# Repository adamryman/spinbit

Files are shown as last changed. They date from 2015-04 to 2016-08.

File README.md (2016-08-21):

# SpinBit: A Wearable Rotation Counter
Katie Kemp, Adam Ryman, Isaac Perry
CSE 477, Spring 2015

spinbit is a piece of open source hardware that counts how many time you spin over time and send that data to your android phone.

See the [Final Report](./spinbit-final-report.pdf)

Web page that includes weekly reports: [spinbit.adamryman.com](http://spinbit.adamryman.com)

You can also see our [Poster](./poster.pdf). It was made in powerpoint in the file poster.pptx, and I, Adam, rendered the poster on linux so the fonts in the pdf may be off.

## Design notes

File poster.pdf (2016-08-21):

SpinBit

Processor | SD Card

Bluetooth Module

Mobile Device

Mobile Application

Gyroscope

### Problem:

Fitness devices, such as the fit bit, have become quite popular. This popularity demonstrates a desire to quantify physical activity. Currently the devices on the market measure little more than a simple pedometer. This works well for activities that are based on running but not for activities based on other modes of movement. Dancing is a popular physical activity and some methods of dancing in particular are rooted in spinning or twirling. Currently there is no fitness device that is designed to quantify spinning as it relates to dancing.

### Introducing SpinBit:

SpinBit is a fitness device specifically targeted for dancers. The device captures the rotations of your body and reports the intensity of your spinning. The accompanying mobile application is used to manage and view your spinning data. This gives you a new insight to your dancing, track trends over time and compete with your friends.

## What it does:

- Locally records relative times between users
spins
- Connects to mobile
device via bluetooth to
transfer data
- Mobile application
allows for user to
display spin data

### How it works:

- On record session initiation, SpinBit samples raw
gyroscope angular velocity data
- Angular velocity is
processed in real time to
determine “spin events”
- “Spin events” are recorded with relative time between events
- In idle mode, mobile device can request spin session
data via bluetooth
- Spin session data is
transferred via bluetooth
- Mobile application stores data and allows the user to visualize it.

# SpinBit: What’s your count?

## How you use it:

- Affix SpinBit to waist
using clip, with long side pointing down
- Turn device on and
press the button to start
recording a spin session
- After finished recording spin session, press
button again
- While device is on, the
mobile application may
be used to request spin
sessions
- Navigate to sessions on
mobile application to
view visualizations of
past spin sessions

### Looking forward:

Within this summer, we plan to release a crowd funding campaign to raise funding to release SpinBit to Seattle’s contra dancers. Using skills learned during this capstone, we plan to:
- Drastically reduce device size by using smaller battery, alternative storage hardware, stacked bluetooth/processor, and improved PCB layout
- Add additional app functionality such as, alternative data visualizations, sharing, and device configurations

Photo source:
https://www.theportlandcollection.com/contra-dancing/

Katie Kemp, Isaac Perry, Adam Ryman

spinbit.adamryman.com

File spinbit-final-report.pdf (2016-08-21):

# SpinBit: A Wearable Rotation Counter

## Katie Kemp, Adam Ryman, Isaac Perry CSE 477, Spring 2015

## ABSTRACT

The quantitative self-movement has created hundreds of niche devices for recording and analyzing specific details of everyday life. In this work, we present SpinBit, a lightweight wearable device that allows the user to locally record and share their average angular velocity. Our system uses a three axis gyroscope/accelerator to evaluate when a user completes a revolution and records that data locally, and allows the user to upload that data to a mobile android device for analysis and sharing. SpinBit has applications in performance arts and dancing where users may want to increase their spins over short or long periods of time and/or compete with other performers in spins. Furthermore, our device is awesome.

## Keywords

Spins, wearable, sensing, gyroscope

## 1. INTRODUCTION

In dancing and performance arts, performers often do not have the capacity to hold a multifunctional device (smartphone) on their person for clothing and/or weight restrictions. This drastically reduces their ability to gather data about their respective performances. We envision a wearable device that is very small and lightweight and self-contained that a user can clip to themselves to gather rotational data.

Currently all smartphones and several other devices that people use regularly have 3 axis gyroscopes already included. Theoretically spin detection should be trivial to implement on these devices in software, but the problem is that these device are either bulky, difficult to attach to a variety of clothing and/or an embedded device that is not easily programmed. SpinBit solves this problem by being designed specifically to do one thing, record spins, and do it very well.

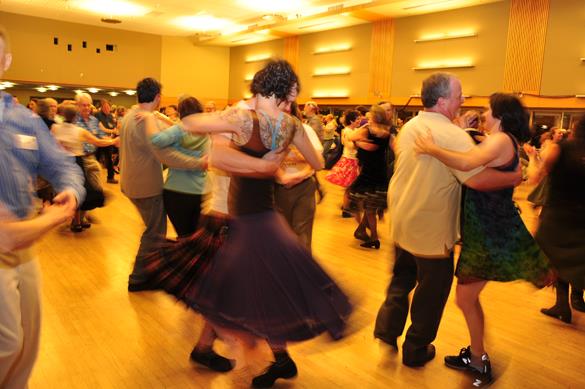
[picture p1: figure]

Figure 1. Contra Dancing is a type of dancing that involves lots of rotations, and thus a fun application of the SpinBit. [1]

## 2. THEORY OF OPERATION

Small lower power gyroscopes have been on the market for several years; their footprint is so small and their power usage so low that they have been incorporated into every smartphone ever created.

MEMS Gyroscopes (the type of gyroscope on circuit boards) use the Coriolis Effect to detect angular velocity along an axis of rotation. The premise is that there is a small object vibrating along a linear axis up and down, and this object affixed to a surrounding structure without impeding its vibrations [2]. If you take the plane that the object is vibrating within and rotate the plane, the object will want to keep moving in its linear direction and will move (from a non-rotating perspective) in the direction opposite of the rotation. The movement brings the vibrating object closer / farther from fixed walls and the capacitance between these objects can be amplified and outputted as the sensor values.

Mounting the gyroscope so that it is parallel to the user’s body in the standing vertical direction, we are able to detect the angular velocity of the user in the plane that is perpendicular to their standing direction.

This angular velocity data can then be integrated to find the users angular position relative to the time the sensor values were first read. Once this angular position exceeds 2*pi radians we record the time that has passed since the last event. This time is logged locally on the device and can be requested via Bluetooth.

## 3. SYSTEM IMPLEMENTATION DETAILS

The SpinBit system consists of a physical device clipped onto the user’s waist band and an app that this clip-on device connects to, where the user can see the spin data collected.

## 3.1 Hardware

The SpinBit uses an ATMEGA328 microcontroller as the central part of the system. There is a button on the device which when pressed by the user signals to the processor that it should begin collecting spin data. When the button is pressed a second time, the device exits data collection mode and waits for a Bluetooth signal from the android phone app requesting spin data.

The microcontroller is connected to a MPU-6050 triple-axis combined gyroscope and accelerometer. When in data collection mode, the processor requests acceleration data from the gyroscope.

The SpinBit stores spinning data in a directory of text files hosted by a microSD card. Every time the processor determines that a spin has happened it notes the time since the device entered data collection mode, and saves this value into storage in a text file created for the current spin session. The SpinBit uses a Bluetooth to communicate with the android application. When the application requests data, the device sends the oldest spin session text file on the microSD card over Bluetooth to the application. When the SpinBit receives conformation from the app that a data set has been successfully sent, it deletes the text file associated with the oldest spin session currently in storage. Whenever the device is powered on and not recording, it is waiting for a command from the mobile device.

There is a reset button that will not be easily accessible to the user as well as pin headers that we used for debugging and programming. The power switch is located on the side, so as to be easily accessible to the user. The SpinBit uses a 3.7V lithium polymer re-chargeable battery. The board that we designed includes as charging IC and micro USB port for charging the battery.

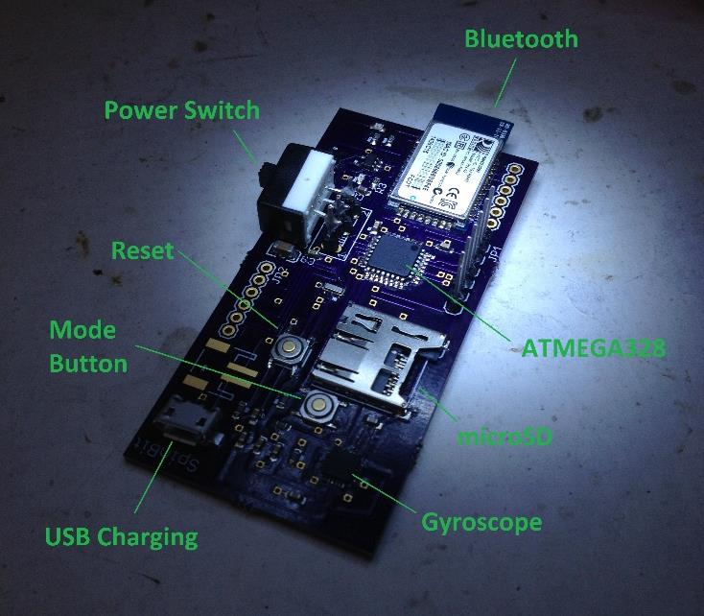
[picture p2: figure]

Figure 2. In an effort to make our prototype device as small as possible, we custom designed the PCB used.

## 3.2 Data Processing

All data processing is currently done on the SpinBit in real time concurrent with data collection. When in data collection mode, the processor requests the angular velocity from the gyroscope. Because of the orientation that the gyroscope is mounted in, we look just at the Y component of the gyroscope data; this component corresponds to the plane of rotation experienced by a dancer wearing the SpinBit in the proper orientation. The value read by the processor from the gyroscope is adjusted based on the current level of sensitivity of the gyroscope to obtain a positional value in degrees. If the processor determines that the user has not changed direction, it adds the degrees rotated to a running sum. When this sum reaches 360 degrees, a spin is logged. If the processor determines that the user has changed direction it checks if the sum is over certain threshold. If the sum is over this threshold it logs a spin before resetting the sum.

The prototype that we are demoing has a simpler version of the data processing on it that does not check to see how far the user has rotated when a change of direction occurs.

## 3.3 Android Application

The main features of the app are to retrieve data sets from the SpinBit and display data sets to the user. These main features require a number of secondary features: Bluetooth configuration; establishing a Bluetooth connection between the mobile device and the SpinBit; requesting datasets into and putting them into permanent storage; and enabling the user to browse different data sets.

The home page of the app has four buttons: “My Spins”, “Download from SpinBit”, “Reconnect” and “Set Up”. “My Spins” will display a list of all the data sets that have previously been downloaded. “Download” requests a data set from the SpinBit and saves it into permanent storage. “Reconnect” initiates the app side of the Bluetooth connection with the SpinBit. “Set Up” allows the user to specify the unique name of the specific SpinBit this mobile application is capable of connecting to.

Before the user employs any of these features there is some initial setup. First, the user must pair their mobile device with the SpinBit. This is done through the settings of the mobile device. Bluetooth should be turned on and the device is visible. Select the name of your SpinBit and the devices will be paired. Now the app needs to connect to the SpinBit.

Initially the app is incapable to making a Bluetooth connection to a SpinBit. In order for the mobile device to connect, the application needs to know identifying information about the Bluetooth module the SpinBit is using to make a connection. The homepage of the app has a “Set Up” button. Pressing this button brings up a dialog where the user can enter the name of the Bluetooth module in the SpinBit. The name is saved as a preference and will persist even after the app is closed. At any time the user can press this button to change the name of the SpinBit the app is able to connect to. This must be done at least once before any other of the apps functions can operate, but once it is done the app is now fully operational.

If the app has a name for the SpinBit it will connect to, it will automatically connect at startup. After specifying a name or if the connection was disturbed, the “Reconnect” button will initiate a new connection between the application and the SpinBit the app knows the name of.

Once the app has been properly set up and is connected with SpinBit, it is ready to receive data. To request a data set from the SpinBit press the “Download” button. This sends a request to the SpinBit, which must be in transfer mode. The SpinBit will send characters over Bluetooth to the mobile device; these characters are stored in a buffer in the app until a specific character sequence that signifies the end of the data set is added to the buffer. This sequence is a newline character followed by a return character (“\r\n”). Once a whole data set has been received a data set object is instantiated which holds the data from the SpinBit, a Timestamp for this data set and a name that the user can set later. This data set object it is added to a library of data set objects, which is implemented with a List. This library is regularly backed up and saved to a JSON file. The data sets in this library can be accessed by the user.

The app lets the user browse their saved data sets, tag information about their data sets, and view visualizations of the data sets. Pressing the “My Spins” button from the home screen displays a list of datasets, ordered chronologically. The data sets of spins have names and timestamps associated with them; these are displayed in the list along with the total number of spins in that set. The user is able to click on a data set and is taken to a new page. This page displays the name of the data set, a graph of the data. The data that is saved are time periods in milliseconds between spins captured by the SpinBit. This data is converted into angular velocity in complete spins per second and the app generates a graph of this trend for the user. Below the graph there are buttons which launch dialogs that allow the user to specify a name for the data set, and modify the date and time for this data set.

## 4. EXPERIMENTAL PROCEDURE AND RESULTS

Most of the testing for the SpinBit consisted of testing each individual section. For instance, we tested parts on a bread board, got what we had connected working before we added more parts. Once we had things working on a breadboard we designed a PCB based off of our breadboard design.

## 4.1 Breadboard Design and Testing

After device conception we quickly ordered parts to build a functional prototype on a breadboard. We used this prototype to test various assumptions about product feasibility. To keep our budget low we ordered the cheapest breakout board components we could find. We chose the atmega processor with the Arduino development board because of it’s easy of use and heavy community support and documentation. After hooking up and configuring each component we built three basic systems, one to put data onto a SD card, one to send data from the SD card to Bluetooth, and one to process the sensor data.

## 4.2 Tests of Spin Detection

Initially we took transferred our raw sensor data to a PC and used Python to get a sense of what processing techniques would give us clean spin detection. The first task was correlating the raw sensor values with actual angular velocities and positions; we did this through a combination of reading our datasheets to find theoretical correlated values and then doing controlled spins to tweak these values for a full 360 degree rotation. After being able to reliably detect a rotation while moving in a single direction, we started work on detecting when the user changed directions and how to deal with partial spins. We eventually determined that we could sense if the user was changing direction by storing a small amount of the previous sensor values in memory and checking if the running sum of sensor values were trending in the other rotational direction. If this was the case we would check how close the user was to completing a rotation and if they were within 80% of a spin we would count that as a spin event. This 80% of a spin check was also run at the end of a spin session to determine if the user had almost made a spin before ending the session.

We then later moved a simpler version of this processing code to the embedded device code.

## 4.3 App Design and Testing

The app was built in many stages, each adding a single feature at a time. The first feature implemented was the home screen, containing four buttons that initially did nothing.

The next step was to implement model object classes that represent a single data set; they store the data, the date, the time and the name of the data set.

The next hurdle was connecting from an android app to an Arduino over Bluetooth. A separate app was made that would simply be able to communicate with an Arduino and toggle an LED. Using an open source app that implemented a Bluetooth connection as a guide, the app was able to connect with another Bluetooth device and exchange data. Then we wrote an Arduino sketch which would listen to serial communication and if it received the correct character it would toggle the LED connected to one of its’ digital output pins. We were able to verify that the Bluetooth connection was working because pressing a button on the app would toggle the state of the LED. Once this was working properly, we added the Bluetooth management code to the home screen implementation in the original app. Before we could test this, we needed to build a SpinBit emulator on an Arduino; this device would wait for a data request, generate a random data set and send it over serial through a Bluetooth module to the application. This was verified using console logs in both the Android and Arduino software. We then added the details of handling data coming from the emulated SpinBit, using that data to instantiate the model objects and save them in a collection. This step was also verified using console logs in the Android application.

While this data could be stored in a collection available to the app, this collection would not persist if the app was closed. We next added the ability to save the contents of the data set collection in a local file on the mobile device. This was verified by logging the contents of the collection to the console, closing the app, and then logging the collection to the console again; the system works properly if the contents of the collection didn’t change after closing the app.

Once the data persisted, the next goal was to add a screen that would allow the user to browse the data sets. There is a screen in the Android library that accepts a collection and displays the contents in a list-view. We were able to confirm this feature was working properly when the contents of the collection logged to the console matched with what was displayed to the user when they launched the new screen.

The purpose of browsing data sets is to choose one and have it visualized for the user. We wanted to create a graph of a single dataset for the user. We were able to find an Android library that would accept an array of data and graph it on a screen. We built a separate app that took an array of fake data and graphed it for the user. It was easy to verify the library worked because we knew how the fake data set should look when graphed. Once this was working properly, we added a feature that when the user clicks on an item in the list-view of data sets, it would first launch a new screen. It also passed the data set to the new screen. In this new screen we included the graphing library and graphed the dataset for the user. We confirmed this was working by comparing the graphs to the data sets logged in the console.

The last features added were displaying more information to the user about the data set with the graph, and adding buttons that let the user modify this information.

We then extensively tested the app by doing everything in our power to break the app. One of the first noticeable bugs was that values would reset (including the values that maintain the Bluetooth connection) when the orientation of the mobile device changed. We were able to fix this issue by changing a setting that forces all of the apps’ screens to retain their state through an orientation change. This also allowed the app to retain its state when it is paused, in the background.

Another issue to be tested was protecting the integrity of the data. We tried exiting the app and shutting down the device in places where the data was being handled. Because the data is saved in a local file and backed up any time it was changed the data was sufficiently protected from corruption.

The last outlet for bugs was the Bluetooth connection. The app was able to handle various edge cases of the data sets: an empty data set, a very large data set, a data set containing negative numbers and a data set containing zeros. Measures were taken in the design of the app to handle each of these scenarios in a reasonable way that doesn’t break the app or cause an inconvenience for the user.

## 4.4 Full-System Testing

The app and the SpinBit device were designed and built separately and the last step for each side was integrating the two halves of the product. The only interface between the two sides of the system is the Bluetooth communication. Because each side was able to independently connect and communicate with other devices, we were able to verify Bluetooth was working for each side properly;

as a result we were able to develop and test both sides knowing only each other’s Bluetooth interface. Partially through the design process, the two teams met to decide on a protocol for transferring data over Bluetooth so that the integration would be seamless. We then went on to design the rest of the project with this protocol in mind. The first time we attempted to integrate the app with the SpinBit we were able to successfully transfer data, save it to the app and display a graph of that data. When gathering this data we periodically spun slowly to fast so that the graph of the data would be recognizable. The graph for this data demonstrated this expectation.

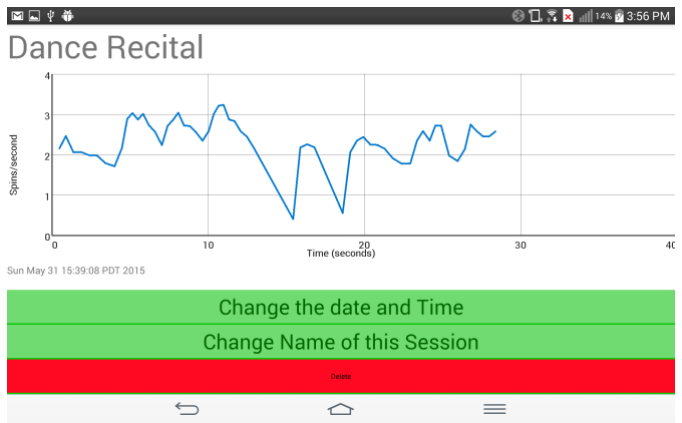
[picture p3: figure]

Figure 3. The graph of a dance session displayed on the mobile device; the peaks and valleys correspond to when the tester was spinning quickly and slowly.

## 5. CHALLENGES

One of the main challenges that we faced was programming the microcontroller on our PCB. When designing the PCB we believed we would be able to program the processor with FTDI pins that were intentionally exposed and soldered to pin headers. It turned out that this was not sufficient for flashing the bootloader onto the microcontroller chip that we are using. In the end we soldered wires directly to the ATMEGA in order to program it. This was a slow process and it frequently required reattaching and often re-soldering wires to the processor just to load a new program onto it; but this did in fact work. We still don’t know how to properly program with the FTDI, and so have been programming with an Arduino Uno as ISP. This means that we are programming at 5V which was not our intent when designing the device. This resulted in various components on the PCB being programmed at a higher voltage than they were specified to be. So while programming we fried our Bluetooth module. Our solution to this was to solder on the 5V Bluetooth module that we used for our breadboard prototype and run it at 3.3V. This seems to be working fine so far.

## 6. FUTURE WORK AND DISCUSSION

In the future we would like to make the device much smaller. We think that this could be done through changing some of the PCB components. The first change that we would make is to use an SPI memory chip instead of the microSD card. The IC for the SPI memory will take up much less space than current microSD card reader. The only downside to using the SPI memory is that we would need to write our own code for memory management instead of being able to use the Arduino SD library.

The second change that we would make is to the Bluetooth module. Instead of the current breakout board that we are using, we would ideally use a low power Bluetooth module. It would also be an improvement if we got a stacked chip such as the RFduino where the Bluetooth module is stacked directly on top of the microcontroller. If we do use a Bluetooth module that is lower power, then our device as a whole would be using less power. Switching from microSD to SPI chip should also reduce the power consumption of parts on the board. With both of these power reductions it could be possible to use a much smaller battery. With all of these size reductions in parts the device as a whole could be much smaller and less noticeable when clipped onto the waistband of the user.

While developing this device there was a lot of discussion as to what should count as a “spin”. Potential users of the SpinBit whom we spoke with all had very different opinions as to what they believe counts as a “spin”. We would like to add multiple spin options that the user can select from. For instance the user could want a spin to be counted only when they have rotated a full 360 degrees, or they may think that moving 180 degrees and then changing directions should count as a spin. There are several ways this could be implemented. One way would be for the user to send a signal from the phone app to tell the microcontroller on the device to process data differently. If we were to implement it this way it would not be possible to change how spins were counted after the data had already been collected. The second way that we could implement this feature would be to process data on the phone side of the system. If we were to implement the feature this way we would have to send all of the data collected by the gyroscope during the spin session over Bluetooth, which could potentially be a lot of data if the session lasts for several hours. The benefit of this would be that the user could go back to logged spin sessions stored on their phone and change the way that spins were processed.

## 7. CONCLUSION

This project was developing the SpinBit, a device for detecting, logging and quantifying the spinning motion of the user. The device is lightweight and can be used completely independently of any other device. It uses real time gyroscope data processing to detect and record spins locally and uses Bluetooth to transfer this data to a mobile device for viewing and sharing. We envision this device to be used by dancers and performance artists to improve their work and satisfy their competitive spirit.

## 8. ACKNOWLEDGMENTS

Our thanks to the CSE and EE departments. Especially to Professor Reynolds and all the people in his lab who helped us when we screwed stuff up.

## 9. REFERENCES

[1] Theportlandcollection.com, 'Contra Dancing', 2015. [Online]. Available: https://www.theportlandcollection.com/contra-dancing
[2] Electroiq.com, 'Introduction to MEMS gyroscopes', 2015.
[Online]. | Available:
http://electroiq.com/blog/2010/11/introduction-to-mems-gyroscopes/

# Columns on Last Page Should Be Made Equal Length

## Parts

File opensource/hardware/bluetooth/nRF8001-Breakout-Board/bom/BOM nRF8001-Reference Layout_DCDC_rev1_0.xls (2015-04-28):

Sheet: Mouser BOM - Table 1
nRF8001 core circuitry Bill of Materials
DC/DC converter enabled
Designator | Value | Footprint | Manufacturer Part # | Mouser Part # | Mouser Price | Quantity | Item Total | Comment
C1, C2 | 18pF | 0603 | VJ0603A100GXACW1BC | 77-VJ0603A100GXACBC | 0.098 | 5 | 0.49 | NP0 +/- 2%
C13, C14 | 9pF | 0603 | GRM1885C1H9R0BZ01D | 81-GRM1885C1H9R0BZ01 | 0.098 | 5 | 0.49 | NP0 +/- 2%
C3 | 2.2nF | 0603 | 77-VJ0603A222GXJPBC | VJ0603A222GXJPW1BC | 0.142 | 3 | 0.426 | X7R +/- 10%
C4 | Not mounted | 0603 |  |  |  | 3 | 0
C5 | 1.8pF | 0603 | VJ0603A1R8BXXCW1BC | 77-VJ0603A1R8BXXCBC | 0.087 | 3 | 0.261 | NP0 +/-0.1pF
C6 | 1.2pF | 0603 | VJ0603A1R2BXACW1BC | 77-VJ0603A1R2BXACBC | 0.087 | 3 | 0.261 | NP0 +/-0.1pF
C7, C9 | 1.0µF | 0603 | C1608X7R1C105KT | 810-C1608X7R1C105K | 0.076 | 5 | 0.38 | X7R +/- 10%
C8 | 1.0nF | 0603 | CC0603KRX7R9BB102 | 603-CC603KRX7R9BB102 | 0.098 | 3 | 0.294 | X7R +/- 10%
C10, C12 | 100nF | 0603 | 0603YC104KAT2A | 581-060316C104K | 0.044 | 5 | 0.22 | X7R +/- 10%
C11 | 33nF | 0603 | C0603C333K4RACTM | 80-C0603C333K4RACTM | 0.076 | 3 | 0.228 | X7R +/- 10%
L1 | 8.2nH | 0603 | CI160808-8N2J | 652-CI160808-8N2J | 0.055 | 3 | 0.165 | High frequency chip inductor +/-5%
L2 | 5.6nH | 0603 | 744761056C | 710-744761056C | 0.36 | 3 | 1.08 | High frequency chip inductor +/-5%
L3 | 3.9nH | 0603 | B82496C3399J | 871-B82496C3399J | 0.382 | 3 | 1.146 | High frequency chip inductor +/-5%
L4 | 10µH | 0603 | MLZ1608M100WT | 810-MLZ1608M100W | 0.087 | 3 | 0.261 | Chip inductor, IDC,min = 50mA, +/-20%
L5 | 15nH | 0603 | L0603C15NJRMST | 80-L0603C15NJRMST | 0.131 | 3 | 0.393 | High frequency chip inductor +/-10%
R1 | 22k | 0603 | AC0603FR-0722KL | 603-AC0603FR-0722KL | 0.022 | 3 | 0.066 | +/-1%
U1 | nRF8001 | QFN32 | nRF8001-R2Q32-T | 949-NRF8001-R2Q32-T | 4.98 | 2 | 9.96 | QFN32 5x5 mm package
X1 | U1 | 3.2 x 2.5 mm | ABM8G-16.000MHZ-B4Y-T | 815-ABM8G-16-B4Y-T | 1.27 | 2 | 2.54 | SMD-3225, 16 MHz, CL=18pF, +/-30 ppm
X2 | 32.768kHz | 3.2 x 1.5 mm | ABS10-32.768KHZ-9-T | 815-ABS10-32.768K9T | 1.08 | 2 | 2.16 | 32.768kHz, Cl=9pF, ±20ppm
 | 2.4GHz |  | A24-HASM-450 | 888-A24-HASM-450 | 6.55 | 1 | 6.55 | Antenna
 |  |  |  |  |  |  | 0
Total |  |  |  |  | 9.173 |  | 27.371
Other Components
Designator | Value | Footprint | Manufacturer Part # |  | Price | Quantity | Item Total | Comment
PCB substrate | FR4 laminate | 18.4 x 16.7 mm |  |  | 1 | 10 | 10 | 2 layer, thickness 1.6 mm, from SeeedStudio
RP SMA |  |  |  |  | 1.95 | 2 | 3.9 | Sparkfun RP SMA
Total |  |  |  |  | 2.95 |  | 13.9
GRAND TOTAL | 41.271

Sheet: Mouser BOM Import - Table 1
C1, C2 | 77-VJ0603A100GXACBC | 10
C13, C14 | 81-GRM1885C1H9R0BZ01 | 10
C3 | VJ0603A222GXJPW1BC | 5
C4 |  | 5
C5 | 77-VJ0603A1R8BXXCBC | 5
C6 | 77-VJ0603A1R2BXACBC | 5
C7, C9 | 810-C1608X7R1C105K | 10
C8 | 603-CC603KRX7R9BB102 | 5
C10, C12 | 581-060316C104K | 10
C11 | 80-C0603C333K4RACTM | 5
L1 | 652-CI160808-8N2J | 5
L2 | 710-744761056C | 5
L3 | 871-B82496C3399J | 5
L4 | 810-MLZ1608M100W | 5
L5 | 80-L0603C15NJRMST | 5
R1 | 603-AC0603FR-0722KL | 5
U1 | 949-NRF8001-R2Q32-T | 2
X1 | 815-ABM8G-16-B4Y-T | 2
X2 | 815-ABS10-32.768K9T | 2

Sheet: Newark BOM - Table 1
nRF8001 core circuitry Bill of Materials
DC/DC converter enabled
Designator | Value | Footprint | Manufacturer Part # | Newark Part # | Newark Price | Comment
C1, C2 | 18pF | 0603 | VJ0603A100GXACW1BC |  |  | NP0 +/- 2%
C13, C14 | 9pF | 0603 | GRM1885C1H9R0BZ01D |  |  | NP0 +/- 2%
C3 | 2.2nF | 0603 | 77-VJ0603A222GXJPBC (http://ca.mouser.com/ProductDetail/Vishay-Vitramon/VJ0603A222GXJPW1BC/) |  |  | X7R +/- 10%
C4 | Not mounted | 0603
C5 | 1.8pF | 0603 | VJ0603A1R8BXXCW1BC |  |  | NP0 +/-0.1pF
C6 | 1.2pF | 0603 | VJ0603A1R2BXACW1BC |  |  | NP0 +/-0.1pF
C7, C9 | 1.0µF | 0603 | C1608X7R1C105KT |  |  | X7R +/- 10%
C8 | 1.0nF | 0603 | CC0603KRX7R9BB102 |  |  | X7R +/- 10%
C10, C12 | 100nF | 0603 | 0603YC104KAT2A |  |  | X7R +/- 10%
C11 | 33nF | 0603 | C0603C333K4RACTM |  |  | X7R +/- 10%
L1 | 8.2nH | 0603 | CI160808-8N2J |  |  | High frequency chip inductor +/-5%
L2 | 5.6nH | 0603 | 744761056C |  |  | High frequency chip inductor +/-5%
L3 | 3.9nH | 0603 | B82496C3399J |  |  | High frequency chip inductor +/-5%
L4 | 10µH | 0603 | MLZ1608M100WT |  |  | Chip inductor, IDC,min = 50mA, +/-20%
L5 | 15nH | 0603 | L0603C15NJRMST |  |  | High frequency chip inductor +/-10%
R1 | 22k | 0603 | AC0603FR-0722KL |  |  | +/-1%
 | nRF8001 | QFN32 | nRF8001-R2Q32-T |  |  | QFN32 5x5 mm package
X1 | U1 | 3.2 x 2.5 mm | ABM8G-16.000MHZ-B4Y-T |  |  | SMD-3225, 16 MHz, CL=18pF, +/-30 ppm
X2 | 32.768kHz | 3.2 x 1.5 mm | ABS10-32.768KHZ-9-T |  |  | 32.768kHz, Cl=9pF, ±20ppm
PCB substrate | FR4 laminate | 18.4 x 16.7 mm |  |  |  | 2 layer, thickness 1.6 mm
Total

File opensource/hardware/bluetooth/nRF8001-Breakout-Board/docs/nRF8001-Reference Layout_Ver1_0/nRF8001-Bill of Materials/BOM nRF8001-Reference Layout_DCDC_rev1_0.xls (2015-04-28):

Date: 2010-12-20
nRF8001 core circuitry Bill of Materials
DC/DC converter enabled
Designator | Value | Footprint | Comment
C1, C2, C13, C14 | 15pF | 0402 | NP0 +/- 2%
C3 | 2.2nF | 0402 | X7R +/- 10%
C4 | Not mounted | 0402
C5 | 1.8pF | 0402 | NP0 +/-0.1pF
C6 | 1.2pF | 0402 | NP0 +/-0.1pF
C7, C9 | 1.0µF | 0603 | X7R +/- 10%
C8 | 1.0nF | 0402 | X7R +/- 10%
C10, C12 | 100nF | 0402 | X7R +/- 10%
C11 | 33nF | 0402 | X7R +/- 10%
L1 | 8.2nH | 0402 | High frequency chip inductor +/-5%
L2 | 5.6nH | 0402 | High frequency chip inductor +/-5%
L3 | 3.9nH | 0402 | High frequency chip inductor +/-5%
L4 | 10µH | 0603 | Chip inductor, IDC,min = 50mA, +/-20%
L5 | 15nH | 0402 | High frequency chip inductor +/-10%
R1 | 22k | 0402 | +/-1%
U1 | nRF8001 | QFN32 | QFN32 5x5 mm package
X1 | 16MHz | 3.2 x 2.5 mm | SMD-3225, 16 MHz, CL=9pF, +/-50 ppm
X2 | 32.768kHz | 3.2 x 1.5 mm | SMD-3215, 32.768kHz, Cl=9pF, ±20ppm
PCB substrate | FR4 laminate | 18.4 x 16.7 mm | 2 layer, thickness 1.6 mm

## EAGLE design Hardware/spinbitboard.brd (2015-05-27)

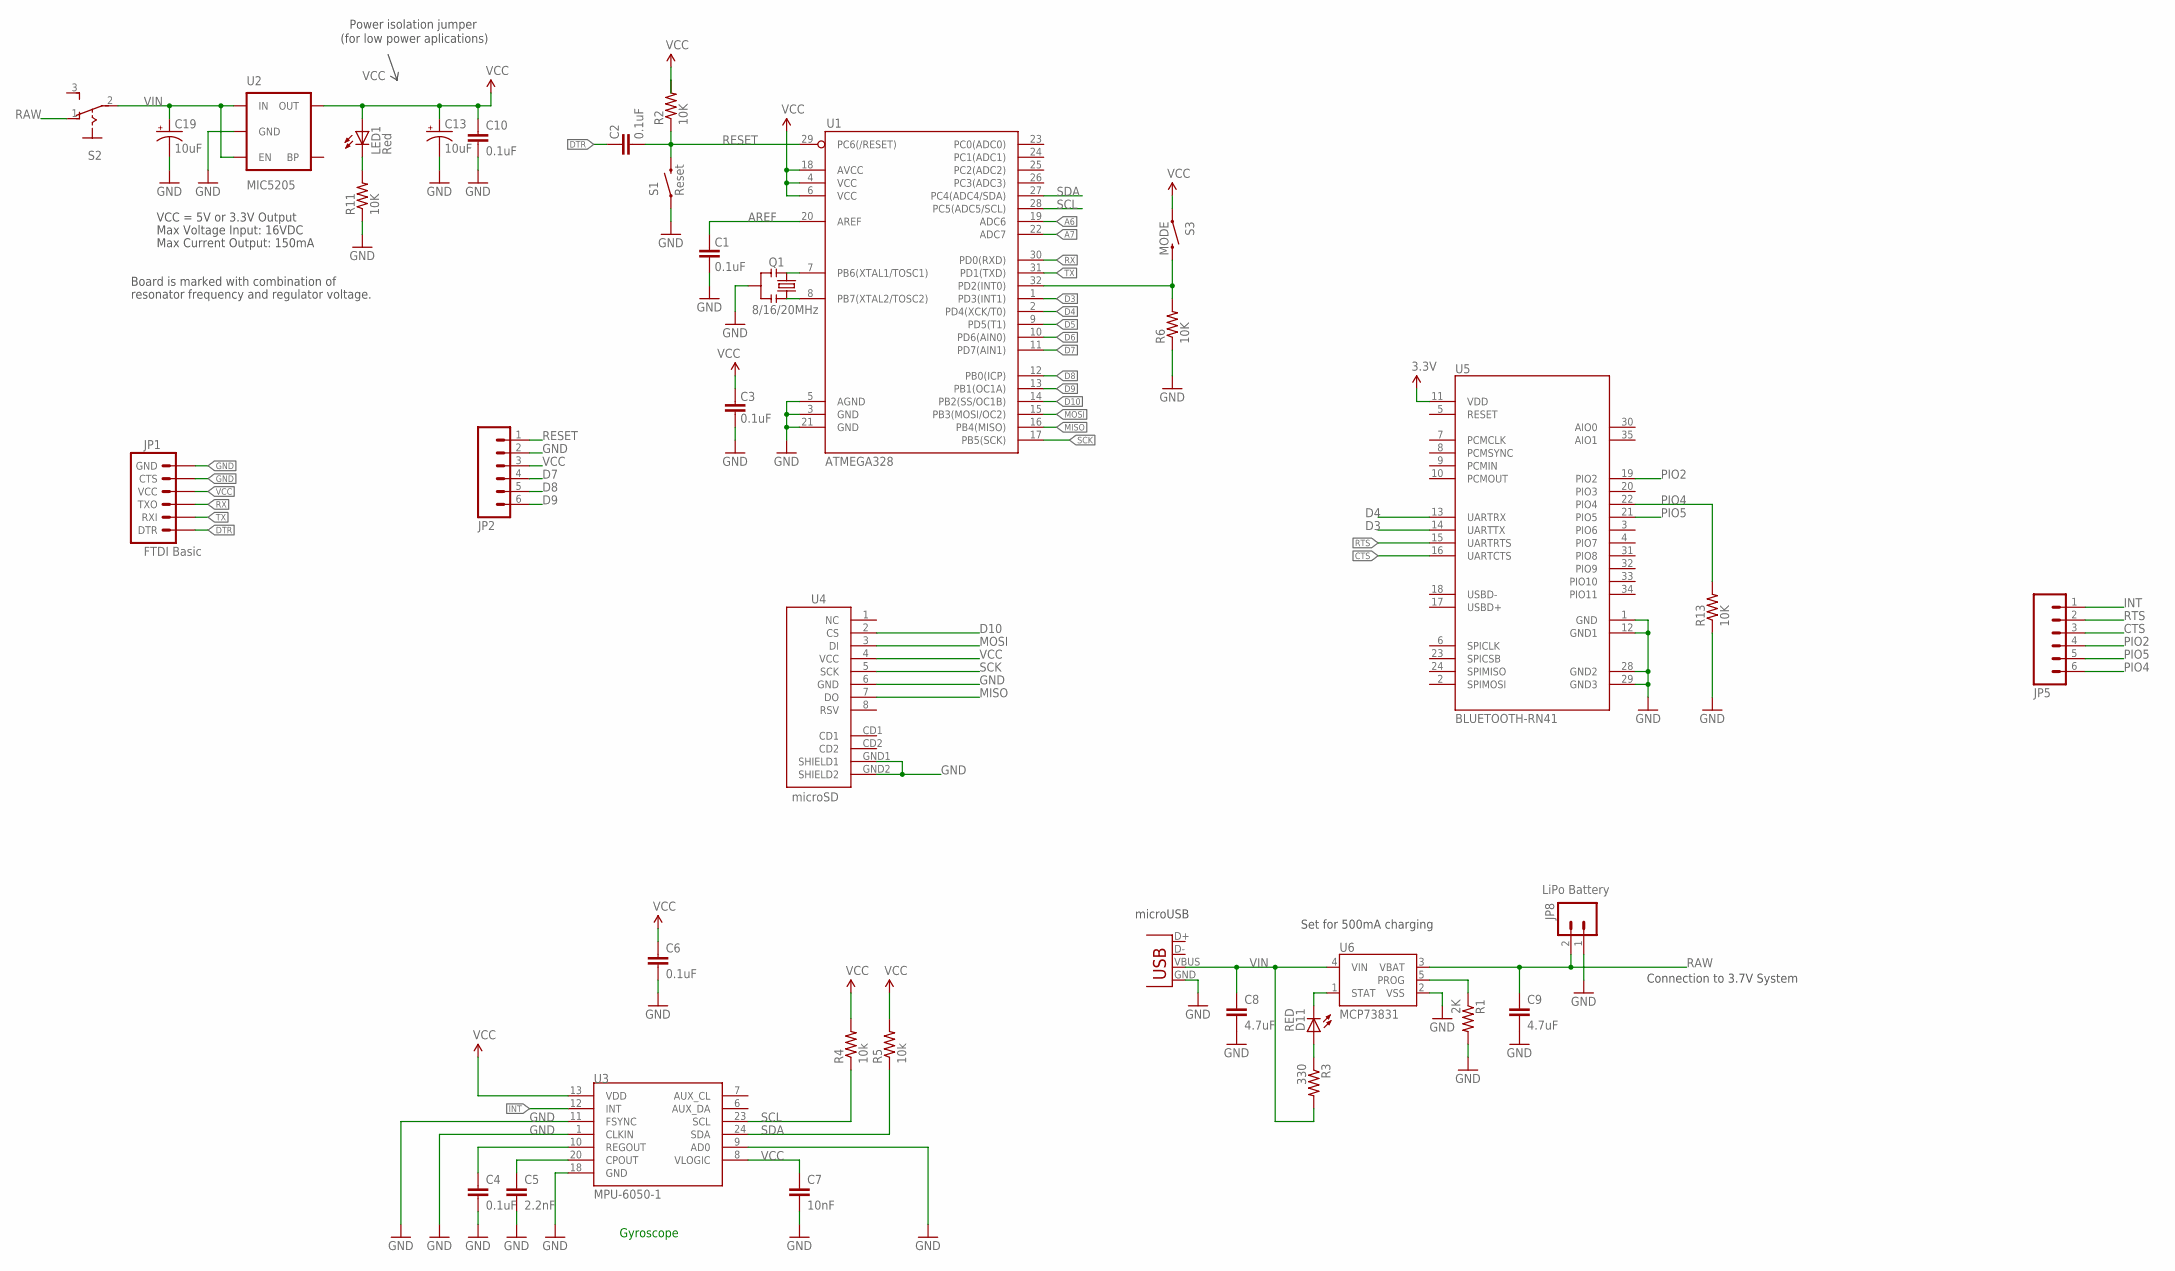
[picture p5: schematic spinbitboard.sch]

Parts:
C1, C2, C3, C4, C6, C10: 0.1uF; 0603-CAP
C5: 2.2nF; 0603-CAP
C7: 10nF; 0603-CAP
C8, C9: 4.7uF; C0603
C13, C19: 10uF; EIA3216
D11: RED; LED-0603
JP1: FTDI Basic; 1X06
JP2, JP5: M06SIP; 1X06
JP8: LiPo Battery; JST-2-SMD
LED1: Red; 0603-LED-ALT1
Q1: 8/16/20MHz; RESONATOR-SMD-1:1
R1: 2K; R0603
R2, R6, R11, R13: 10K; 0603-RES
R3: 330; R0603
R4, R5: 10k; 0603-RES
S1: Reset; TACTILE-SWITCH-SMD-ALT01
S2: 255SB
S3: MODE; TACTILE-SWITCH-SMD-ALT01
U1: ATMEGA328; TQFP32-08
U2: MIC5205; SOT23-5
U3: MPU-6050-1; QFN-24-4MM2
U4: microSD; MICRO-SD-SOCKET-PP
U5: BLUETOOTH-RN41; RN41
U6: MCP73831; SOT23-5
X1: Micro USB; USB-MICROB

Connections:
3.3V: C6.1, R4.2, R5.2, S3.1, S3.2 (1), U3.13 (VDD)
A6: U1.19 (ADC6)
A7: U1.22 (ADC7)
AREF: C1.2, U1.20 (AREF)
CTS: JP5.3, U5.16 (UARTCTS)
D2: R6.2, S3.3 (2), S3.4 (2), U1.32 (PD2(INT0))
D3: U1.1 (PD3(INT1)), U5.14 (UARTTX)
D4: U1.2 (PD4(XCK/T0)), U5.13 (UARTRX)
D5: U1.9 (PD5(T1))
D6: U1.10 (PD6(AIN0))
D7: JP2.4, U1.11 (PD7(AIN1))
D8: JP2.5, U1.12 (PB0(ICP))
D9: JP2.6, U1.13 (PB1(OC1A))
D10: U1.14 (PB2(SS/OC1B)), U4.2 (CS)
DTR: C2.2, JP1.1 (DTR)
GND: C1.1, C3.1, C4.2, C5.2, C6.2, C7.2, C8.2, C9.2, C10.2, C13.C (-), C19.C (-), JP1.5 (CTS), JP1.6 (GND), JP2.2, JP8.1, Q1.2, R1.2, R6.1, R11.1, R13.1, S1.1, S1.2 (1), U1.3 (GND), U1.5 (AGND), U1.21 (GND), U2.2 (GND), U3.1 (CLKIN), U3.9 (AD0), U3.11 (FSYNC), U3.18 (GND), U4.6 (GND), U4.GND1 (SHIELD1), U4.GND2 (SHIELD2), U5.1 (GND), U5.12 (GND1), U5.28 (GND2), U5.29 (GND3), U6.2 (VSS), X1.GND
INT: JP5.1, U3.12 (INT)
MISO: U1.16 (PB4(MISO)), U4.7 (DO)
MOSI: U1.15 (PB3(MOSI/OC2)), U4.3 (DI)
unnamed: Q1.3, U1.8 (PB7(XTAL2/TOSC2))
unnamed: Q1.1, U1.7 (PB6(XTAL1/TOSC1))
unnamed: LED1.C, R11.2
unnamed: C5.1, U3.20 (CPOUT)
unnamed: C4.1, U3.10 (REGOUT)
unnamed: D11.A, R3.1
PIO2: JP5.4, U5.19 (PIO2)
PIO4: JP5.6, R13.2, U5.22 (PIO4)
PIO5: JP5.5, U5.21 (PIO5)
PROG: R1.1, U6.5 (PROG)
RAW: C9.1, JP8.2, S2.1 (O), U6.3 (VBAT)
RESET: C2.1, JP2.1, R2.1, S1.3 (2), S1.4 (2), U1.29 (PC6(/RESET))
RTS: JP5.2, U5.15 (UARTRTS)
RX: JP1.3 (TXO), U1.30 (PD0(RXD))
SCK: U1.17 (PB5(SCK)), U4.5 (SCK)
SCL: R4.1, U1.28 (PC5(ADC5/SCL)), U3.23 (SCL)
SDA: R5.1, U1.27 (PC4(ADC4/SDA)), U3.24 (SDA)
STAT: D11.C, U6.1 (STAT)
TX: JP1.2 (RXI), U1.31 (PD1(TXD))
VCC: C3.2, C7.1, C10.1, C13.A (+), JP1.4 (VCC), JP2.3, LED1.A, R2.2, U1.4 (VCC), U1.6 (VCC), U1.18 (AVCC), U2.5 (OUT), U3.8 (VLOGIC), U4.4 (VCC), U5.11 (VDD)
VIN: C8.1, C19.A (+), R3.2, S2.2, U2.1 (IN), U2.3 (EN), U6.4 (VIN), X1.VBUS

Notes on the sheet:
Max Voltage Input: 16VDC
Max Current Output: 150mA
Board is marked with combination of
resonator frequency and regulator voltage.
VCC = 5V or 3.3V Output
Power isolation jumper
(for low power aplications)
Gyroscope
Set for 500mA charging
Connection to 3.7V System
microUSB

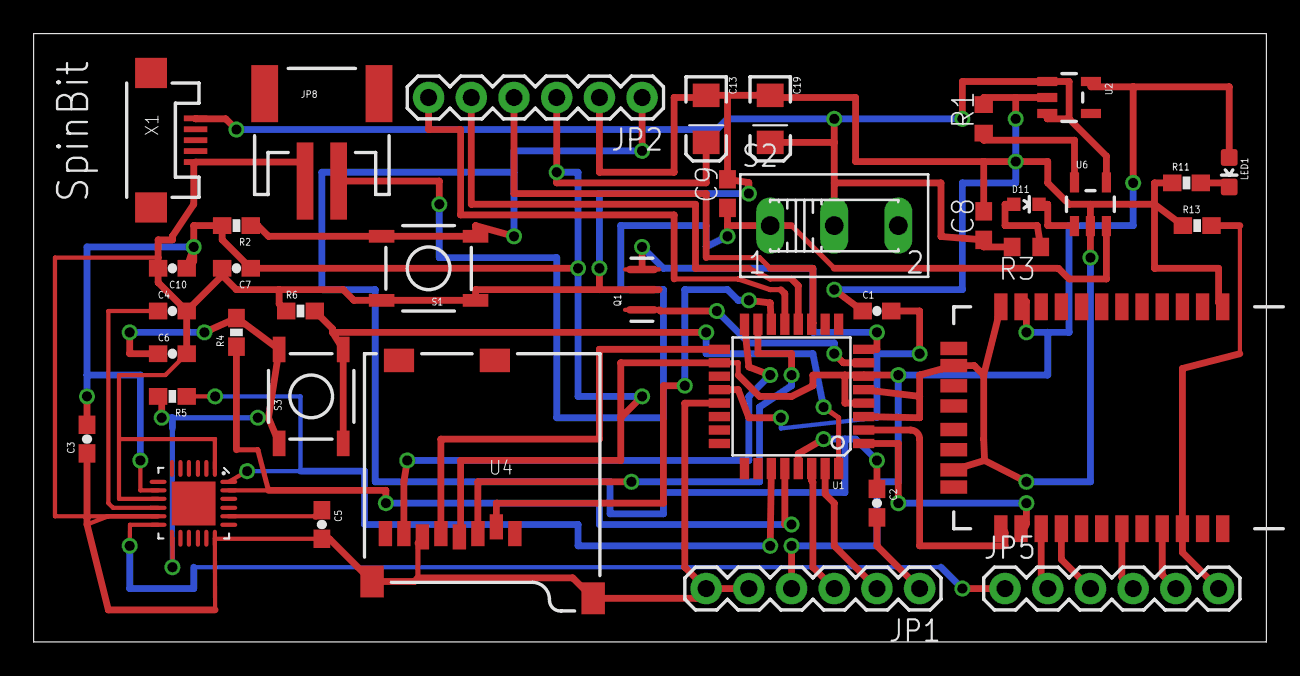
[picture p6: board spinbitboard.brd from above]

Board: 2 copper layers, 73.3 x 36.2 mm, 37 parts (0 on the bottom side), 36 nets.

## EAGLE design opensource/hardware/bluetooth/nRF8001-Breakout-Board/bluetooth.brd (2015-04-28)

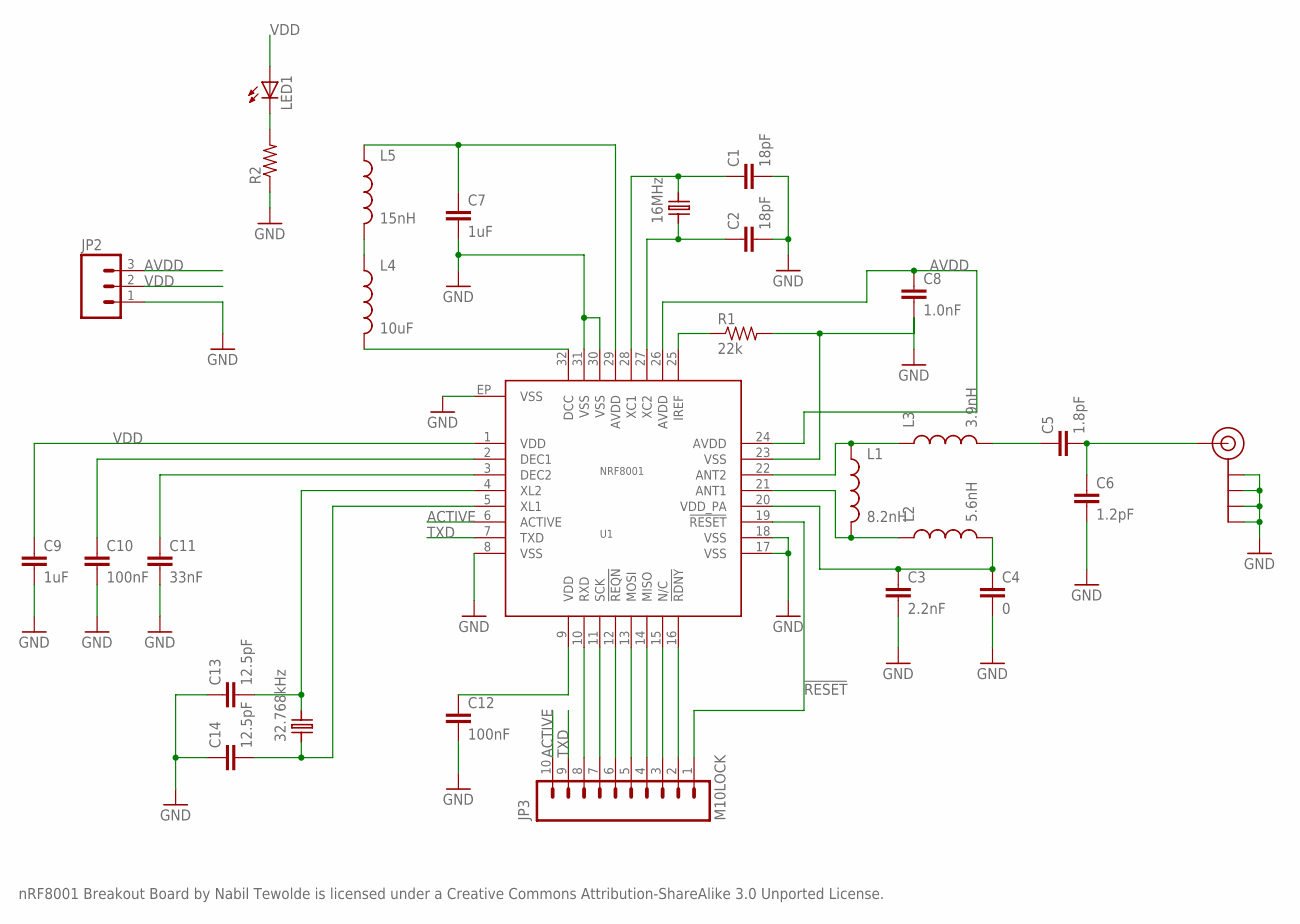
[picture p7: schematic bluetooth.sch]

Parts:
C1, C2: 18pF; 0603-CAP
C3: 2.2nF; 0603-CAP
C4: 0; 0603-CAP
C5: 1.8pF; 0603-CAP
C6: 1.2pF; 0603-CAP
C7, C9: 1uF; 0603-CAP
C8: 1.0nF; 0603-CAP
C10, C12: 100nF; 0603-CAP
C11: 33nF; 0603-CAP
C13, C14: 12.5pF; 0603-CAP
J$1: SMA_EDGE; SMA-EDGE
JP2: M03LOCK; 1X03_LOCK
JP3: M10LOCK; 1X10_LOCK
L1: 8.2nH; 0603
L2: 5.6nH; 0603
L3: 3.9nH; 0603
L4: 10uF; 0603
L5: 15nH; 0603
LED1: LED0603; LED-0603
R1: 22k; 0603-RES
R2: RESISTOR0603-RES; 0603-RES
U1: NRF8001; QFN-32
X1: 16MHz; CRYSTAL-2.5X3.5
X2: 32.768kHz; CRYSTAL-ABS10

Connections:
!RESET: JP3.1, U1.19 (!RESET)
ACTIVE: JP3.10, U1.6 (ACTIVE)
AVDD: C8.1, JP2.3, U1.24 (AVDD), U1.26 (AVDD)
GND: C1.2, C2.2, C3.2, C4.2, C6.2, C7.2, C8.2, C9.2, C10.2, C11.2, C12.2, C13.1, C14.1, J$1.GND@0 (GND), J$1.GND@1 (GND), J$1.GND@2 (GND), J$1.GND@3 (GND), JP2.1, R1.2, R2.1, U1.8 (VSS), U1.17 (VSS), U1.18 (VSS), U1.23 (VSS), U1.30 (VSS), U1.31 (VSS), U1.EP (VSS)
unnamed: L4.1, L5.2
unnamed: L4.2, U1.32 (DCC)
unnamed: L1.1, L3.1, U1.22 (ANT2)
unnamed: C7.1, L5.1, U1.29 (AVDD)
unnamed: LED1.C, R2.2
unnamed: C10.1, U1.2 (DEC1)
unnamed: C11.1, U1.3 (DEC2)
unnamed: L1.2, L2.1, U1.21 (ANT1)
unnamed: C5.1, L3.2
unnamed: C5.2, C6.1, J$1.SIG (SIGNAL)
unnamed: R1.1, U1.25 (IREF)
unnamed: C3.1, C4.1, L2.2, U1.20 (VDD_PA)
unnamed: C2.1, U1.27 (XC2), X1.P$1
unnamed: C1.1, U1.28 (XC1), X1.P$3
unnamed: C13.2, U1.4 (XL2), X2.P$2
unnamed: C14.2, U1.5 (XL1), X2.P$1
unnamed: JP3.2, U1.16 (!RDNY)
unnamed: JP3.3, U1.15 (N/C)
unnamed: JP3.4, U1.14 (MISO)
unnamed: JP3.5, U1.13 (MOSI)
unnamed: JP3.6, U1.12 (!REQN)
unnamed: JP3.7, U1.11 (SCK)
unnamed: JP3.8, U1.10 (RXD)
TXD: JP3.9, U1.7 (TXD)
VDD: C9.1, C12.1, JP2.2, LED1.A, U1.1 (VDD), U1.9 (VDD)

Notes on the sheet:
nRF8001 Breakout Board by Nabil Tewolde is licensed under a Creative Commons Attribution-ShareAlike 3.0 Unported License.

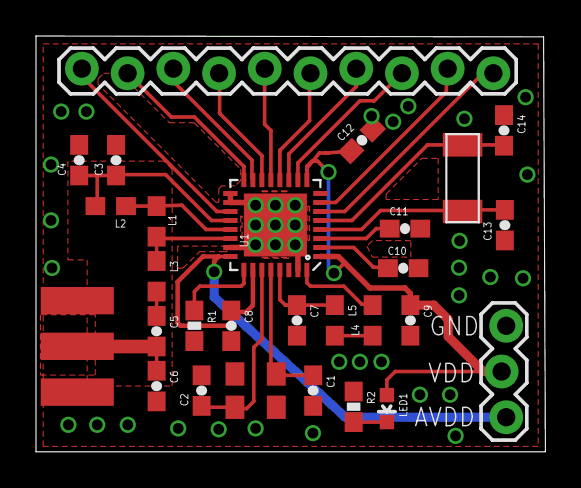
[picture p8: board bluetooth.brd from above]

Board: 2 copper layers, 28.3 x 23.1 mm, 28 parts (0 on the bottom side), 29 nets.

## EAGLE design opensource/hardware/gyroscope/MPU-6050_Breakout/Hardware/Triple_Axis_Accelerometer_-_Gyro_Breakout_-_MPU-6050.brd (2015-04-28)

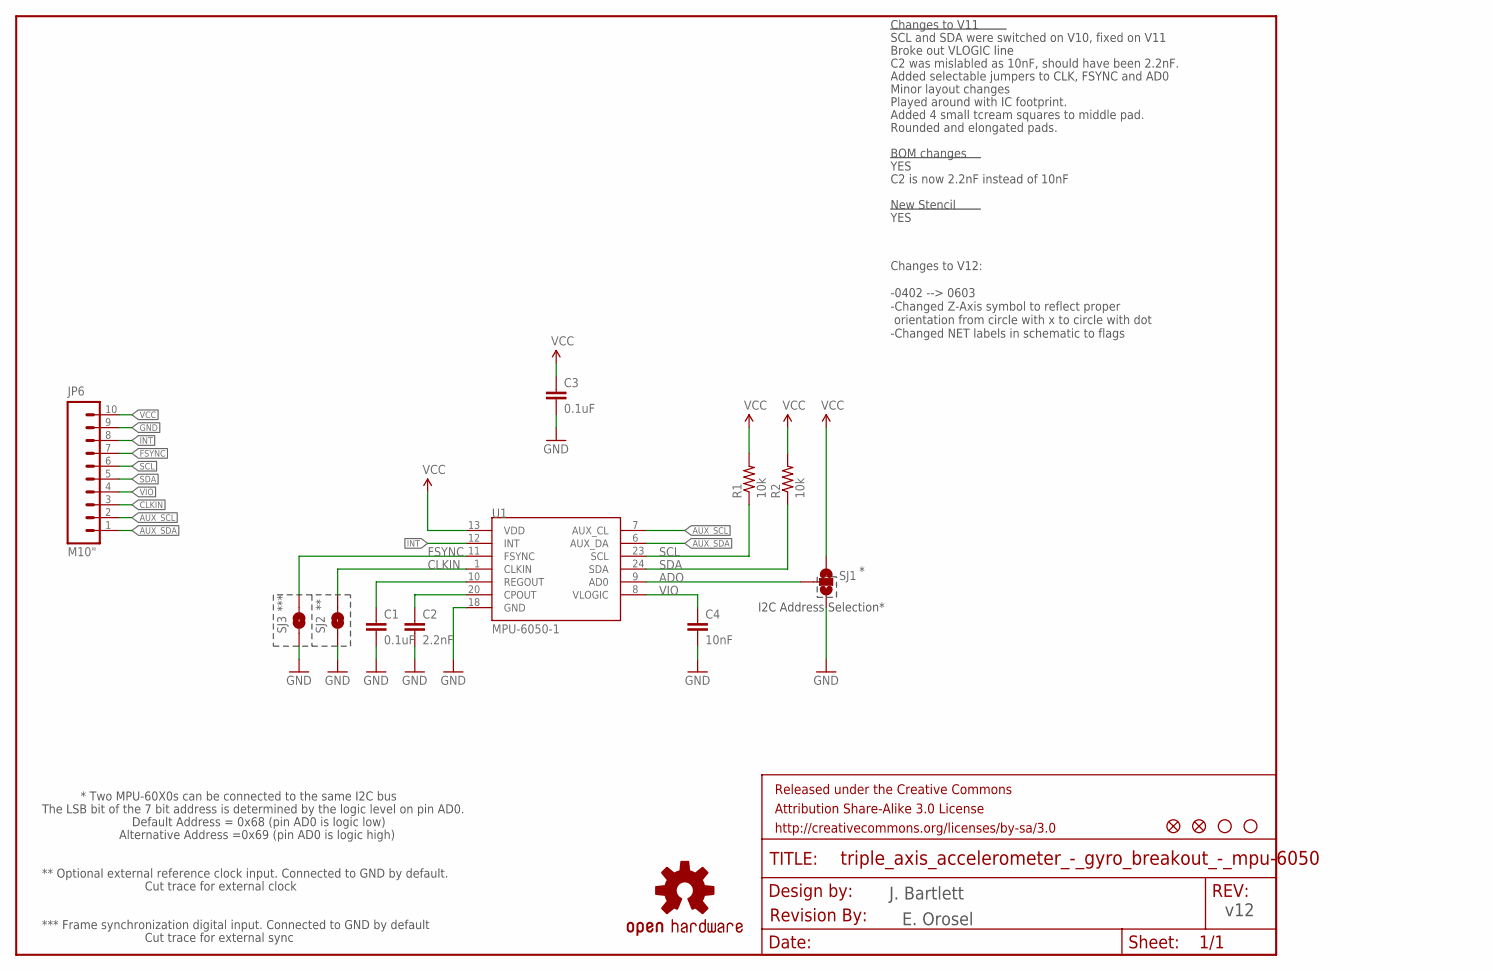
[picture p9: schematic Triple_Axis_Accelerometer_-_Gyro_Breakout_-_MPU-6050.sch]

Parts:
C1, C3: 0.1uF; 0603-CAP
C2: 2.2nF; 0603-CAP
C4: 10nF; 0603-CAP
FRAME1: FRAME-LETTER; CREATIVE_COMMONS
JP2, JP5: FIDUCIALUFIDUCIAL; MICRO-FIDUCIAL
JP3, JP4: STAND-OFFTIGHT; STAND-OFF-TIGHT
JP6: M10"; 1X10
R1, R2: 10k; 0603-RES
SJ1: SOLDERJUMPER_2WAYPASTE2&3; SJ_3_PASTE2&3
SJ2, SJ3: SOLDERJUMPERTRACE; SJ_2S-TRACE
U1: MPU-6050-1; QFN-24-4MM2
U$1: OSHW-LOGOS; OSHW-LOGO-S
U$5: REVISION

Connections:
ADO: SJ1.2, U1.9 (AD0)
AUX_SCL: JP6.2, U1.7 (AUX_CL)
AUX_SDA: JP6.1, U1.6 (AUX_DA)
CLKIN: JP6.3, SJ2.2, U1.1 (CLKIN)
FSYNC: JP6.7, SJ3.2, U1.11 (FSYNC)
GND: C1.2, C2.2, C3.2, C4.2, JP6.9, SJ1.3, SJ2.1, SJ3.1, U1.18 (GND)
INT: JP6.8, U1.12 (INT)
unnamed: C2.1, U1.20 (CPOUT)
unnamed: C1.1, U1.10 (REGOUT)
SCL: JP6.6, R1.1, U1.23 (SCL)
SDA: JP6.5, R2.1, U1.24 (SDA)
VCC: C3.1, JP6.10, R1.2, R2.2, SJ1.1, U1.13 (VDD)
VIO: C4.1, JP6.4, U1.8 (VLOGIC)

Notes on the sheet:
J. Bartlett
I2C Address Selection*
*** Frame synchronization digital input. Connected to GND by default
***
Cut trace for external sync
* Two MPU-60X0s can be connected to the same I2C bus
Default Address = 0x68 (pin AD0 is logic low)
Alternative Address =0x69 (pin AD0 is logic high)
The LSB bit of the 7 bit address is determined by the logic level on pin AD0.
** Optional external reference clock input. Connected to GND by default.
Cut trace for external clock
Changes to V11
SCL and SDA were switched on V10, fixed on V11
C2 was mislabled as 10nF, should have been 2.2nF.
Broke out VLOGIC line
BOM changes
New Stencil
YES
C2 is now 2.2nF instead of 10nF
Minor layout changes
Added selectable jumpers to CLK, FSYNC and AD0
Played around with IC footprint.
Changes to V12: -0402 --> 0603 -Changed Z-Axis symbol to reflect proper orientation from circle with x to circle with dot -Changed NET labels in schematic to flags
E. Orosel
v12
Added 4 small tcream squares to middle pad.
Rounded and elongated pads.

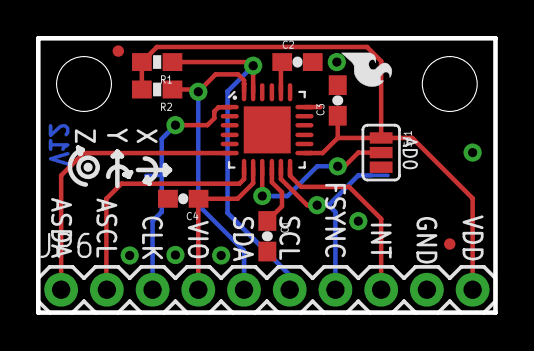
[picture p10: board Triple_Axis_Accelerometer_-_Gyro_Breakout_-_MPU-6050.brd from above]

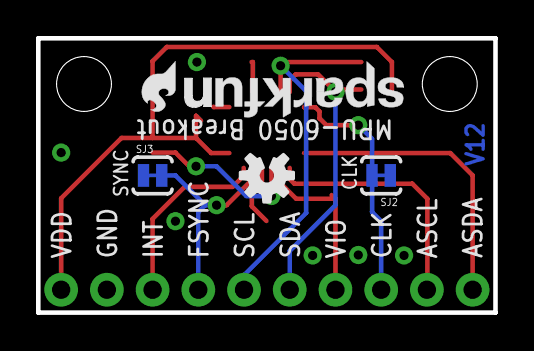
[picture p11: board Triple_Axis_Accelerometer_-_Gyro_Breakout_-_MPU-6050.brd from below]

Board: 2 copper layers, 25.4 x 15.2 mm, 21 parts (5 on the bottom side), 13 nets.

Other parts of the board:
U$2, U$3: SFE-LOGO-FLAME
U$4: SFE-NEW-WEB

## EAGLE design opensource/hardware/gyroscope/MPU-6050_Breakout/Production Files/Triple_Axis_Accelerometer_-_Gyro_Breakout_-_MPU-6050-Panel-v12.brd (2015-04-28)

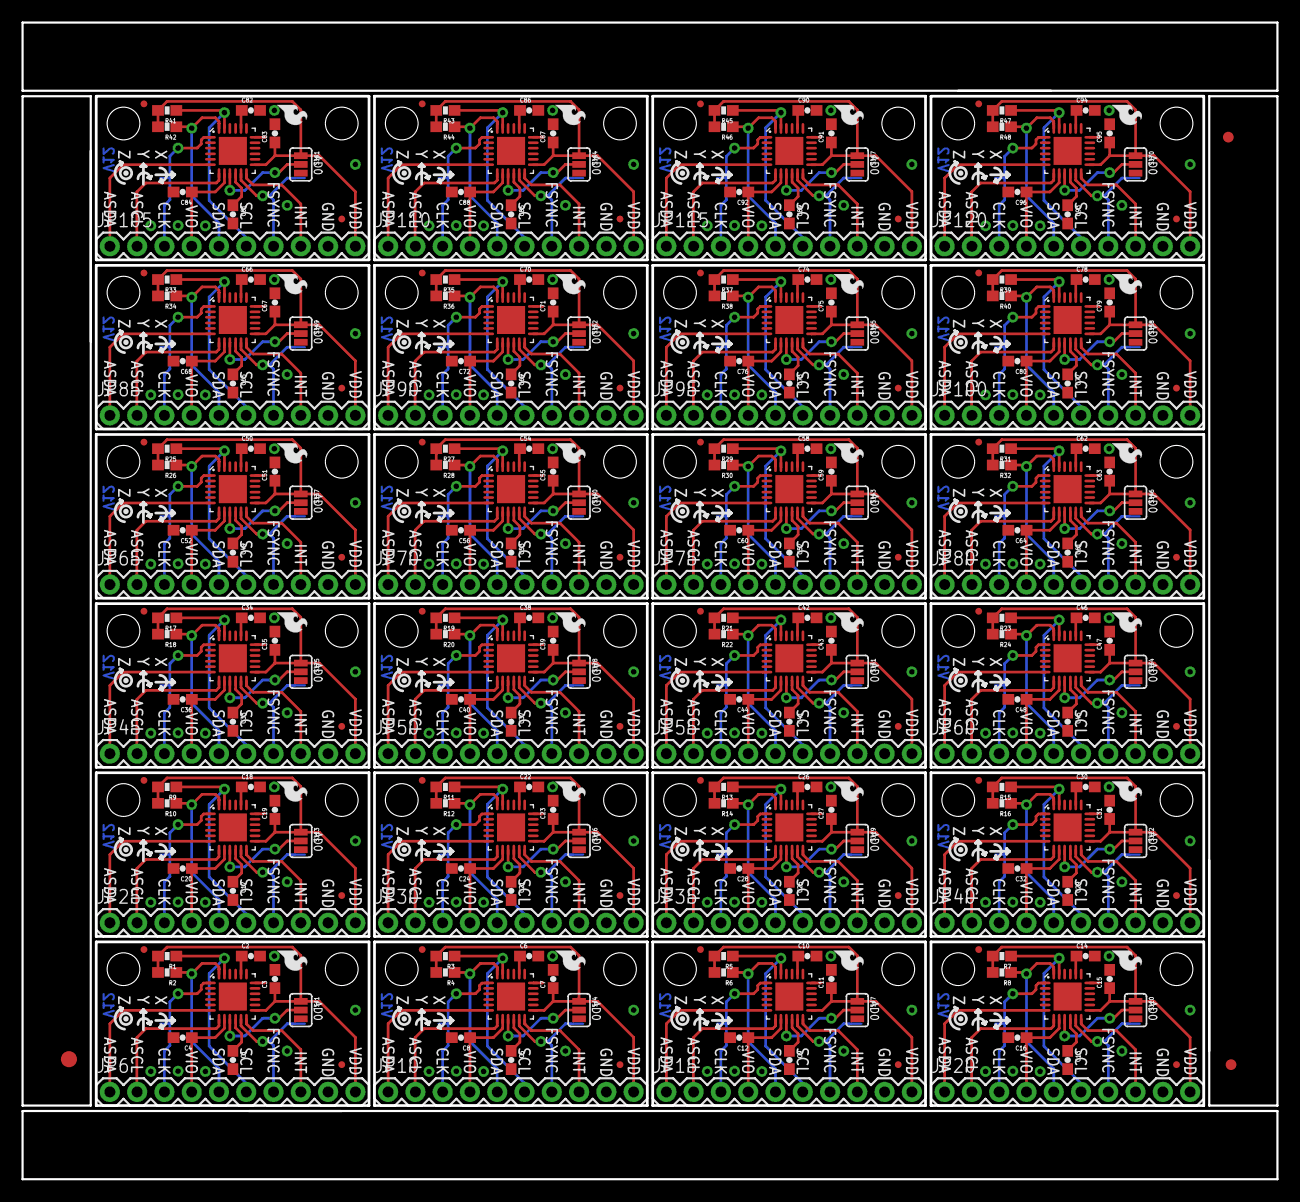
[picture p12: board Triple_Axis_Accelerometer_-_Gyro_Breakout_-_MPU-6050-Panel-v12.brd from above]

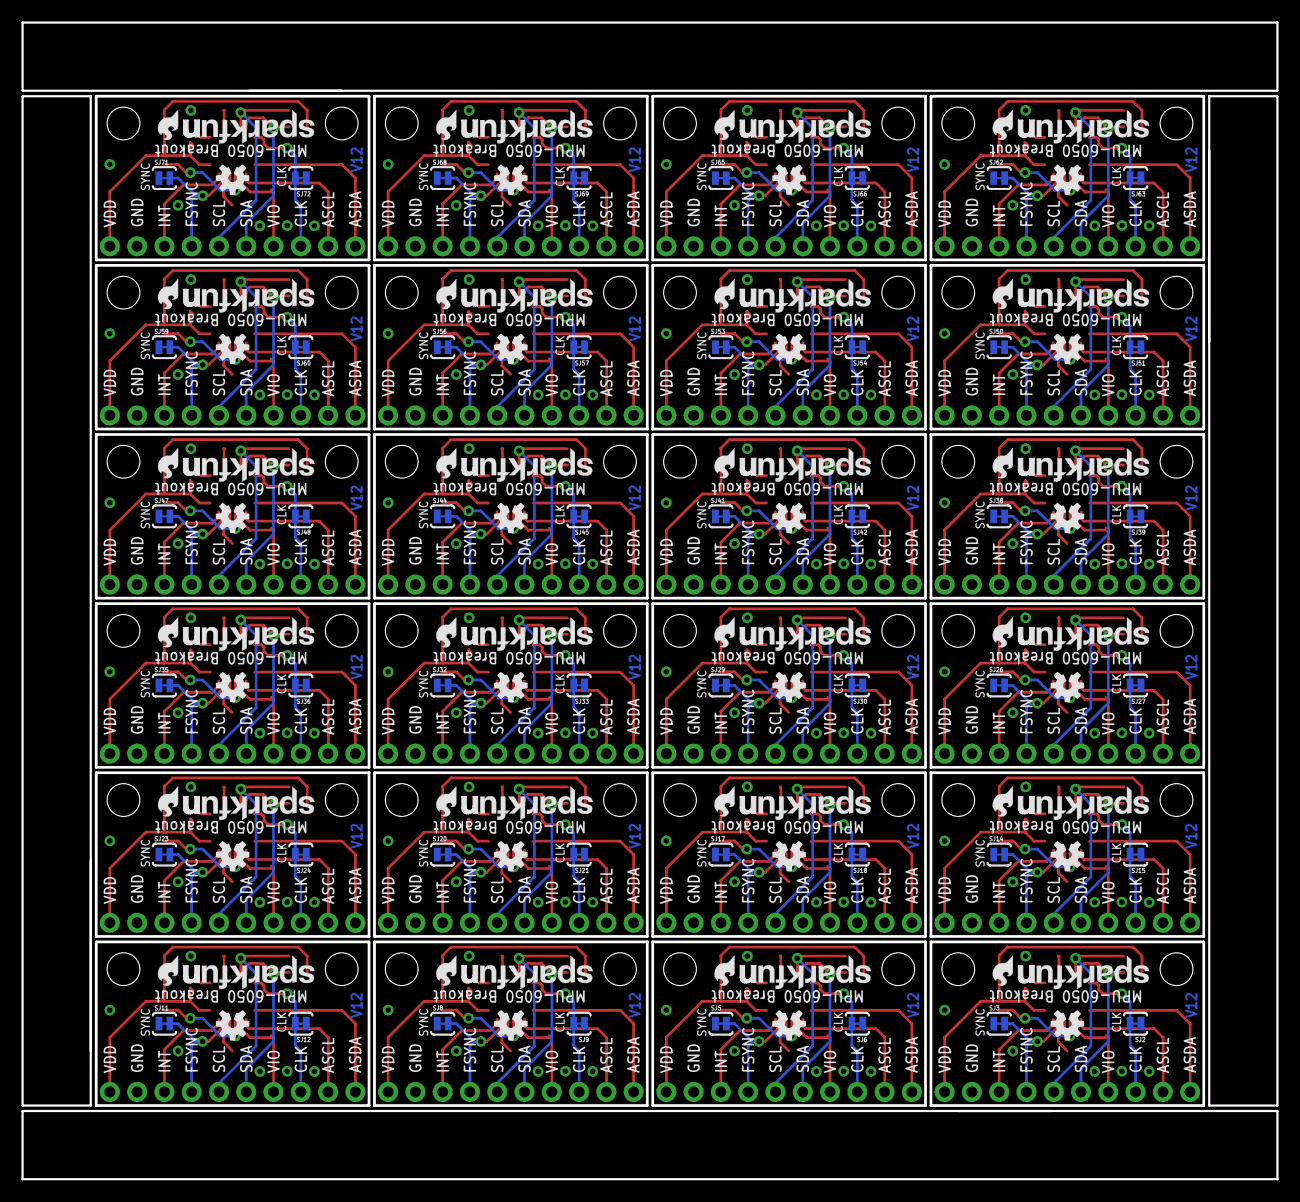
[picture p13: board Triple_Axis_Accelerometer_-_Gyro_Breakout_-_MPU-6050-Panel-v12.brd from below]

Board: 2 copper layers, 116.8 x 107.7 mm, 459 parts (120 on the bottom side), 312 nets.

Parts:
C1, C3, C5, C7, C9, C11, C13, C15, C17, C19, C21, C23, C25, C27, C29, C31, C33, C35, C37, C39, C41, C43, C45, C47, C49, C51, C53, C55, C57, C59, C61, C63, C65, C67, C69, C71, C73, C75, C77, C79, C81, C83, C85, C87, C89, C91, C93, C95: 0.1uF; 0603-CAP
C2, C6, C10, C14, C18, C22, C26, C30, C34, C38, C42, C46, C50, C54, C58, C62, C66, C70, C74, C78, C82, C86, C90, C94: 2.2nF; 0603-CAP
C4, C8, C12, C16, C20, C24, C28, C32, C36, C40, C44, C48, C52, C56, C60, C64, C68, C72, C76, C80, C84, C88, C92, C96: 10nF; 0603-CAP
E$1: FIDUCIAL-1.5X3
E$4, E$5: FIDUCIAL-1X2
JP1, JP3, JP4, JP7, JP11, JP12, JP16, JP17, JP21, JP22, JP26, JP27, JP31, JP32, JP36, JP37, JP41, JP42, JP46, JP47, JP51, JP52, JP56, JP57, JP61, JP62, JP66, JP67, JP71, JP72, JP76, JP77, JP81, JP82, JP86, JP87, JP91, JP92, JP96, JP97, JP101, JP102, JP106, JP107, JP111, JP112, JP116, JP117: STAND-OFFTIGHT; STAND-OFF-TIGHT
JP2, JP5, JP8, JP9, JP13, JP14, JP18, JP19, JP23, JP24, JP28, JP29, JP33, JP34, JP38, JP39, JP43, JP44, JP48, JP49, JP53, JP54, JP58, JP59, JP63, JP64, JP68, JP69, JP73, JP74, JP78, JP79, JP83, JP84, JP88, JP89, JP93, JP94, JP98, JP99, JP103, JP104, JP108, JP109, JP113, JP114, JP118, JP119: FIDUCIALUFIDUCIAL; MICRO-FIDUCIAL
JP6, JP10, JP15, JP20, JP25, JP30, JP35, JP40, JP45, JP50, JP55, JP60, JP65, JP70, JP75, JP80, JP85, JP90, JP95, JP100, JP105, JP110, JP115, JP120: M10"; 1X10
R1, R2, R3, R4, R5, R6, R7, R8, R9, R10, R11, R12, R13, R14, R15, R16, R17, R18, R19, R20, R21, R22, R23, R24, R25, R26, R27, R28, R29, R30, R31, R32, R33, R34, R35, R36, R37, R38, R39, R40, R41, R42, R43, R44, R45, R46, R47, R48: 10k; 0603-RES
SJ1, SJ4, SJ7, SJ10, SJ13, SJ16, SJ19, SJ22, SJ25, SJ28, SJ31, SJ34, SJ37, SJ40, SJ43, SJ46, SJ49, SJ52, SJ55, SJ58, SJ61, SJ64, SJ67, SJ70: SJ_3_PASTE2&3
SJ2, SJ3, SJ5, SJ6, SJ8, SJ9, SJ11, SJ12, SJ14, SJ15, SJ17, SJ18, SJ20, SJ21, SJ23, SJ24, SJ26, SJ27, SJ29, SJ30, SJ32, SJ33, SJ35, SJ36, SJ38, SJ39, SJ41, SJ42, SJ44, SJ45, SJ47, SJ48, SJ50, SJ51, SJ53, SJ54, SJ56, SJ57, SJ59, SJ60, SJ62, SJ63, SJ65, SJ66, SJ68, SJ69, SJ71, SJ72: SJ_2S-TRACE
U1, U2, U3, U4, U5, U6, U7, U8, U9, U10, U11, U12, U13, U14, U15, U16, U17, U18, U19, U20, U21, U22, U23, U24: MPU-6050-1; QFN-24-4MM2
U$1, U$6, U$10, U$14, U$18, U$22, U$26, U$30, U$34, U$38, U$42, U$46, U$50, U$54, U$58, U$62, U$66, U$70, U$74, U$78, U$82, U$86, U$90, U$94: OSHW-LOGOS; OSHW-LOGO-S
U$2, U$3, U$5, U$7, U$9, U$11, U$13, U$15, U$17, U$19, U$21, U$23, U$25, U$27, U$29, U$31, U$33, U$35, U$37, U$39, U$41, U$43, U$45, U$47, U$49, U$51, U$53, U$55, U$57, U$59, U$61, U$63, U$65, U$67, U$69, U$71, U$73, U$75, U$77, U$79, U$81, U$83, U$85, U$87, U$89, U$91, U$93, U$95: SFE-LOGO-FLAME
U$4, U$8, U$12, U$16, U$20, U$24, U$28, U$32, U$36, U$40, U$44, U$48, U$52, U$56, U$60, U$64, U$68, U$72, U$76, U$80, U$84, U$88, U$92, U$96: SFE-NEW-WEB

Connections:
ADO: SJ1.2, U1.9
ADO1: SJ4.2, U2.9
ADO2: SJ7.2, U3.9
ADO3: SJ10.2, U4.9
ADO4: SJ13.2, U5.9
ADO5: SJ16.2, U6.9
ADO6: SJ19.2, U7.9
ADO7: SJ22.2, U8.9
ADO8: SJ25.2, U9.9
ADO9: SJ28.2, U10.9
ADO10: SJ31.2, U11.9
ADO11: SJ34.2, U12.9
ADO12: SJ37.2, U13.9
ADO13: SJ40.2, U14.9
ADO14: SJ43.2, U15.9
ADO15: SJ46.2, U16.9
ADO16: SJ49.2, U17.9
ADO17: SJ52.2, U18.9
ADO18: SJ55.2, U19.9
ADO19: SJ58.2, U20.9
ADO20: SJ61.2, U21.9
ADO21: SJ64.2, U22.9
ADO22: SJ67.2, U23.9
ADO23: SJ70.2, U24.9
AUX_SCL: JP6.2, U1.7
AUX_SCL1: JP10.2, U2.7
AUX_SCL2: JP15.2, U3.7
AUX_SCL3: JP20.2, U4.7
AUX_SCL4: JP25.2, U5.7
AUX_SCL5: JP30.2, U6.7
AUX_SCL6: JP35.2, U7.7
AUX_SCL7: JP40.2, U8.7
AUX_SCL8: JP45.2, U9.7
AUX_SCL9: JP50.2, U10.7
AUX_SCL10: JP55.2, U11.7
AUX_SCL11: JP60.2, U12.7
AUX_SCL12: JP65.2, U13.7
AUX_SCL13: JP70.2, U14.7
AUX_SCL14: JP75.2, U15.7
AUX_SCL15: JP80.2, U16.7
AUX_SCL16: JP85.2, U17.7
AUX_SCL17: JP90.2, U18.7
AUX_SCL18: JP95.2, U19.7
AUX_SCL19: JP100.2, U20.7
AUX_SCL20: JP105.2, U21.7
AUX_SCL21: JP110.2, U22.7
AUX_SCL22: JP115.2, U23.7
AUX_SCL23: JP120.2, U24.7
AUX_SDA: JP6.1, U1.6
AUX_SDA1: JP10.1, U2.6
AUX_SDA2: JP15.1, U3.6
AUX_SDA3: JP20.1, U4.6
AUX_SDA4: JP25.1, U5.6
AUX_SDA5: JP30.1, U6.6
AUX_SDA6: JP35.1, U7.6
AUX_SDA7: JP40.1, U8.6
AUX_SDA8: JP45.1, U9.6
AUX_SDA9: JP50.1, U10.6
AUX_SDA10: JP55.1, U11.6
AUX_SDA11: JP60.1, U12.6
AUX_SDA12: JP65.1, U13.6
AUX_SDA13: JP70.1, U14.6
AUX_SDA14: JP75.1, U15.6
AUX_SDA15: JP80.1, U16.6
AUX_SDA16: JP85.1, U17.6
AUX_SDA17: JP90.1, U18.6
AUX_SDA18: JP95.1, U19.6
AUX_SDA19: JP100.1, U20.6
AUX_SDA20: JP105.1, U21.6
AUX_SDA21: JP110.1, U22.6
AUX_SDA22: JP115.1, U23.6
AUX_SDA23: JP120.1, U24.6
CLKIN: JP6.3, SJ2.2, U1.1
CLKIN1: JP10.3, SJ6.2, U2.1
CLKIN2: JP15.3, SJ9.2, U3.1
CLKIN3: JP20.3, SJ12.2, U4.1
CLKIN4: JP25.3, SJ15.2, U5.1
CLKIN5: JP30.3, SJ18.2, U6.1
CLKIN6: JP35.3, SJ21.2, U7.1
CLKIN7: JP40.3, SJ24.2, U8.1
CLKIN8: JP45.3, SJ27.2, U9.1
CLKIN9: JP50.3, SJ30.2, U10.1
CLKIN10: JP55.3, SJ33.2, U11.1
CLKIN11: JP60.3, SJ36.2, U12.1
CLKIN12: JP65.3, SJ39.2, U13.1
CLKIN13: JP70.3, SJ42.2, U14.1
CLKIN14: JP75.3, SJ45.2, U15.1
CLKIN15: JP80.3, SJ48.2, U16.1
CLKIN16: JP85.3, SJ51.2, U17.1
CLKIN17: JP90.3, SJ54.2, U18.1
CLKIN18: JP95.3, SJ57.2, U19.1
CLKIN19: JP100.3, SJ60.2, U20.1
CLKIN20: JP105.3, SJ63.2, U21.1
CLKIN21: JP110.3, SJ66.2, U22.1
CLKIN22: JP115.3, SJ69.2, U23.1
CLKIN23: JP120.3, SJ72.2, U24.1
FSYNC: JP6.7, SJ3.2, U1.11
FSYNC1: JP10.7, SJ5.2, U2.11
FSYNC2: JP15.7, SJ8.2, U3.11
FSYNC3: JP20.7, SJ11.2, U4.11
FSYNC4: JP25.7, SJ14.2, U5.11
FSYNC5: JP30.7, SJ17.2, U6.11
FSYNC6: JP35.7, SJ20.2, U7.11
FSYNC7: JP40.7, SJ23.2, U8.11
FSYNC8: JP45.7, SJ26.2, U9.11
FSYNC9: JP50.7, SJ29.2, U10.11
FSYNC10: JP55.7, SJ32.2, U11.11
FSYNC11: JP60.7, SJ35.2, U12.11
FSYNC12: JP65.7, SJ38.2, U13.11
FSYNC13: JP70.7, SJ41.2, U14.11
FSYNC14: JP75.7, SJ44.2, U15.11
FSYNC15: JP80.7, SJ47.2, U16.11
FSYNC16: JP85.7, SJ50.2, U17.11
FSYNC17: JP90.7, SJ53.2, U18.11
FSYNC18: JP95.7, SJ56.2, U19.11
FSYNC19: JP100.7, SJ59.2, U20.11
FSYNC20: JP105.7, SJ62.2, U21.11
FSYNC21: JP110.7, SJ65.2, U22.11
FSYNC22: JP115.7, SJ68.2, U23.11
FSYNC23: JP120.7, SJ71.2, U24.11
GND: C1.2, C2.2, C3.2, C4.2, JP6.9, SJ1.3, SJ2.1, SJ3.1, U1.18
GND1: C5.2, C6.2, C7.2, C8.2, JP10.9, SJ4.3, SJ5.1, SJ6.1, U2.18
GND2: C9.2, C10.2, C11.2, C12.2, JP15.9, SJ7.3, SJ8.1, SJ9.1, U3.18
GND3: C13.2, C14.2, C15.2, C16.2, JP20.9, SJ10.3, SJ11.1, SJ12.1, U4.18
GND4: C17.2, C18.2, C19.2, C20.2, JP25.9, SJ13.3, SJ14.1, SJ15.1, U5.18
GND5: C21.2, C22.2, C23.2, C24.2, JP30.9, SJ16.3, SJ17.1, SJ18.1, U6.18
GND6: C25.2, C26.2, C27.2, C28.2, JP35.9, SJ19.3, SJ20.1, SJ21.1, U7.18
GND7: C29.2, C30.2, C31.2, C32.2, JP40.9, SJ22.3, SJ23.1, SJ24.1, U8.18
GND8: C33.2, C34.2, C35.2, C36.2, JP45.9, SJ25.3, SJ26.1, SJ27.1, U9.18
GND9: C37.2, C38.2, C39.2, C40.2, JP50.9, SJ28.3, SJ29.1, SJ30.1, U10.18
GND10: C41.2, C42.2, C43.2, C44.2, JP55.9, SJ31.3, SJ32.1, SJ33.1, U11.18
GND11: C45.2, C46.2, C47.2, C48.2, JP60.9, SJ34.3, SJ35.1, SJ36.1, U12.18
GND12: C49.2, C50.2, C51.2, C52.2, JP65.9, SJ37.3, SJ38.1, SJ39.1, U13.18
GND13: C53.2, C54.2, C55.2, C56.2, JP70.9, SJ40.3, SJ41.1, SJ42.1, U14.18
GND14: C57.2, C58.2, C59.2, C60.2, JP75.9, SJ43.3, SJ44.1, SJ45.1, U15.18
GND15: C61.2, C62.2, C63.2, C64.2, JP80.9, SJ46.3, SJ47.1, SJ48.1, U16.18
GND16: C65.2, C66.2, C67.2, C68.2, JP85.9, SJ49.3, SJ50.1, SJ51.1, U17.18
GND17: C69.2, C70.2, C71.2, C72.2, JP90.9, SJ52.3, SJ53.1, SJ54.1, U18.18
GND18: C73.2, C74.2, C75.2, C76.2, JP95.9, SJ55.3, SJ56.1, SJ57.1, U19.18
GND19: C77.2, C78.2, C79.2, C80.2, JP100.9, SJ58.3, SJ59.1, SJ60.1, U20.18
GND20: C81.2, C82.2, C83.2, C84.2, JP105.9, SJ61.3, SJ62.1, SJ63.1, U21.18
GND21: C85.2, C86.2, C87.2, C88.2, JP110.9, SJ64.3, SJ65.1, SJ66.1, U22.18
GND22: C89.2, C90.2, C91.2, C92.2, JP115.9, SJ67.3, SJ68.1, SJ69.1, U23.18
GND23: C93.2, C94.2, C95.2, C96.2, JP120.9, SJ70.3, SJ71.1, SJ72.1, U24.18
INT: JP6.8, U1.12
INT1: JP10.8, U2.12
INT2: JP15.8, U3.12
INT3: JP20.8, U4.12
INT4: JP25.8, U5.12
INT5: JP30.8, U6.12
INT6: JP35.8, U7.12
INT7: JP40.8, U8.12
INT8: JP45.8, U9.12
INT9: JP50.8, U10.12
INT10: JP55.8, U11.12
INT11: JP60.8, U12.12
INT12: JP65.8, U13.12
INT13: JP70.8, U14.12
INT14: JP75.8, U15.12
INT15: JP80.8, U16.12
INT16: JP85.8, U17.12
INT17: JP90.8, U18.12
INT18: JP95.8, U19.12
INT19: JP100.8, U20.12
INT20: JP105.8, U21.12
INT21: JP110.8, U22.12
INT22: JP115.8, U23.12
INT23: JP120.8, U24.12
unnamed: C6.1, U2.20
unnamed: C5.1, U2.10
unnamed: C2.1, U1.20
unnamed: C10.1, U3.20
unnamed: C1.1, U1.10
unnamed: C9.1, U3.10
unnamed: C14.1, U4.20
unnamed: C13.1, U4.10
unnamed: C18.1, U5.20
unnamed: C17.1, U5.10
unnamed: C22.1, U6.20
unnamed: C21.1, U6.10
unnamed: C26.1, U7.20
unnamed: C25.1, U7.10
unnamed: C30.1, U8.20
unnamed: C29.1, U8.10
unnamed: C34.1, U9.20
unnamed: C33.1, U9.10
unnamed: C38.1, U10.20
unnamed: C37.1, U10.10
unnamed: C42.1, U11.20
unnamed: C41.1, U11.10
unnamed: C46.1, U12.20
unnamed: C45.1, U12.10
unnamed: C50.1, U13.20
unnamed: C49.1, U13.10
unnamed: C54.1, U14.20
unnamed: C53.1, U14.10
unnamed: C58.1, U15.20
unnamed: C57.1, U15.10
unnamed: C62.1, U16.20
unnamed: C61.1, U16.10
unnamed: C66.1, U17.20
unnamed: C65.1, U17.10
unnamed: C70.1, U18.20
unnamed: C69.1, U18.10
unnamed: C74.1, U19.20
unnamed: C73.1, U19.10
unnamed: C78.1, U20.20
unnamed: C77.1, U20.10
unnamed: C82.1, U21.20
unnamed: C81.1, U21.10
unnamed: C86.1, U22.20
unnamed: C85.1, U22.10
unnamed: C90.1, U23.20
unnamed: C89.1, U23.10
unnamed: C94.1, U24.20
unnamed: C93.1, U24.10
SCL: JP6.6, R1.1, U1.23
SCL1: JP10.6, R3.1, U2.23
SCL2: JP15.6, R5.1, U3.23
SCL3: JP20.6, R7.1, U4.23
SCL4: JP25.6, R9.1, U5.23
SCL5: JP30.6, R11.1, U6.23
SCL6: JP35.6, R13.1, U7.23
SCL7: JP40.6, R15.1, U8.23
SCL8: JP45.6, R17.1, U9.23
SCL9: JP50.6, R19.1, U10.23
SCL10: JP55.6, R21.1, U11.23
SCL11: JP60.6, R23.1, U12.23
SCL12: JP65.6, R25.1, U13.23
SCL13: JP70.6, R27.1, U14.23
SCL14: JP75.6, R29.1, U15.23
SCL15: JP80.6, R31.1, U16.23
SCL16: JP85.6, R33.1, U17.23
SCL17: JP90.6, R35.1, U18.23
SCL18: JP95.6, R37.1, U19.23
SCL19: JP100.6, R39.1, U20.23
SCL20: JP105.6, R41.1, U21.23
SCL21: JP110.6, R43.1, U22.23
SCL22: JP115.6, R45.1, U23.23
SCL23: JP120.6, R47.1, U24.23
SDA: JP6.5, R2.1, U1.24
SDA1: JP10.5, R4.1, U2.24
SDA2: JP15.5, R6.1, U3.24
SDA3: JP20.5, R8.1, U4.24
SDA4: JP25.5, R10.1, U5.24
SDA5: JP30.5, R12.1, U6.24
SDA6: JP35.5, R14.1, U7.24
SDA7: JP40.5, R16.1, U8.24
SDA8: JP45.5, R18.1, U9.24
SDA9: JP50.5, R20.1, U10.24
SDA10: JP55.5, R22.1, U11.24
SDA11: JP60.5, R24.1, U12.24
SDA12: JP65.5, R26.1, U13.24
SDA13: JP70.5, R28.1, U14.24
SDA14: JP75.5, R30.1, U15.24
SDA15: JP80.5, R32.1, U16.24
SDA16: JP85.5, R34.1, U17.24
SDA17: JP90.5, R36.1, U18.24
SDA18: JP95.5, R38.1, U19.24
SDA19: JP100.5, R40.1, U20.24
SDA20: JP105.5, R42.1, U21.24
SDA21: JP110.5, R44.1, U22.24
SDA22: JP115.5, R46.1, U23.24
SDA23: JP120.5, R48.1, U24.24
VCC: C3.1, JP6.10, R1.2, R2.2, SJ1.1, U1.13
VCC1: C7.1, JP10.10, R3.2, R4.2, SJ4.1, U2.13
VCC2: C11.1, JP15.10, R5.2, R6.2, SJ7.1, U3.13
VCC3: C15.1, JP20.10, R7.2, R8.2, SJ10.1, U4.13
VCC4: C19.1, JP25.10, R9.2, R10.2, SJ13.1, U5.13
VCC5: C23.1, JP30.10, R11.2, R12.2, SJ16.1, U6.13
VCC6: C27.1, JP35.10, R13.2, R14.2, SJ19.1, U7.13
VCC7: C31.1, JP40.10, R15.2, R16.2, SJ22.1, U8.13
VCC8: C35.1, JP45.10, R17.2, R18.2, SJ25.1, U9.13
VCC9: C39.1, JP50.10, R19.2, R20.2, SJ28.1, U10.13
VCC10: C43.1, JP55.10, R21.2, R22.2, SJ31.1, U11.13
VCC11: C47.1, JP60.10, R23.2, R24.2, SJ34.1, U12.13
VCC12: C51.1, JP65.10, R25.2, R26.2, SJ37.1, U13.13
VCC13: C55.1, JP70.10, R27.2, R28.2, SJ40.1, U14.13
VCC14: C59.1, JP75.10, R29.2, R30.2, SJ43.1, U15.13
VCC15: C63.1, JP80.10, R31.2, R32.2, SJ46.1, U16.13
VCC16: C67.1, JP85.10, R33.2, R34.2, SJ49.1, U17.13
VCC17: C71.1, JP90.10, R35.2, R36.2, SJ52.1, U18.13
VCC18: C75.1, JP95.10, R37.2, R38.2, SJ55.1, U19.13
VCC19: C79.1, JP100.10, R39.2, R40.2, SJ58.1, U20.13
VCC20: C83.1, JP105.10, R41.2, R42.2, SJ61.1, U21.13
VCC21: C87.1, JP110.10, R43.2, R44.2, SJ64.1, U22.13
VCC22: C91.1, JP115.10, R45.2, R46.2, SJ67.1, U23.13
VCC23: C95.1, JP120.10, R47.2, R48.2, SJ70.1, U24.13
VIO: C4.1, JP6.4, U1.8
VIO1: C8.1, JP10.4, U2.8
VIO2: C12.1, JP15.4, U3.8
VIO3: C16.1, JP20.4, U4.8
VIO4: C20.1, JP25.4, U5.8
VIO5: C24.1, JP30.4, U6.8
VIO6: C28.1, JP35.4, U7.8
VIO7: C32.1, JP40.4, U8.8
VIO8: C36.1, JP45.4, U9.8
VIO9: C40.1, JP50.4, U10.8
VIO10: C44.1, JP55.4, U11.8
VIO11: C48.1, JP60.4, U12.8
VIO12: C52.1, JP65.4, U13.8
VIO13: C56.1, JP70.4, U14.8
VIO14: C60.1, JP75.4, U15.8
VIO15: C64.1, JP80.4, U16.8
VIO16: C68.1, JP85.4, U17.8
VIO17: C72.1, JP90.4, U18.8
VIO18: C76.1, JP95.4, U19.8
VIO19: C80.1, JP100.4, U20.8
VIO20: C84.1, JP105.4, U21.8
VIO21: C88.1, JP110.4, U22.8
VIO22: C92.1, JP115.4, U23.8
VIO23: C96.1, JP120.4, U24.8

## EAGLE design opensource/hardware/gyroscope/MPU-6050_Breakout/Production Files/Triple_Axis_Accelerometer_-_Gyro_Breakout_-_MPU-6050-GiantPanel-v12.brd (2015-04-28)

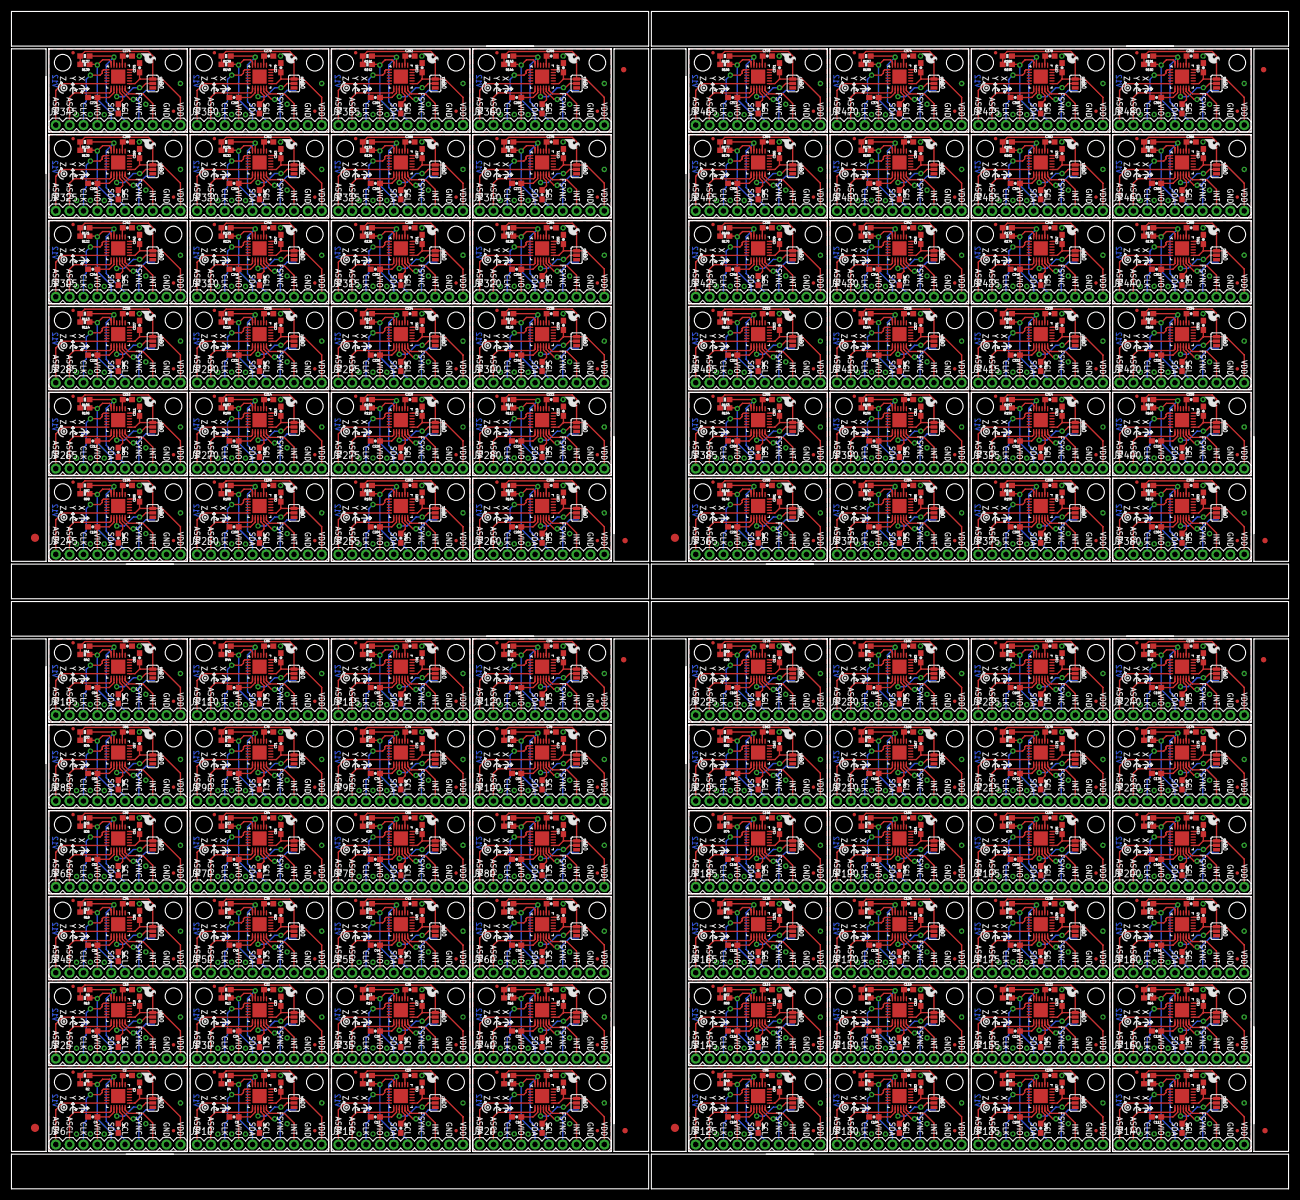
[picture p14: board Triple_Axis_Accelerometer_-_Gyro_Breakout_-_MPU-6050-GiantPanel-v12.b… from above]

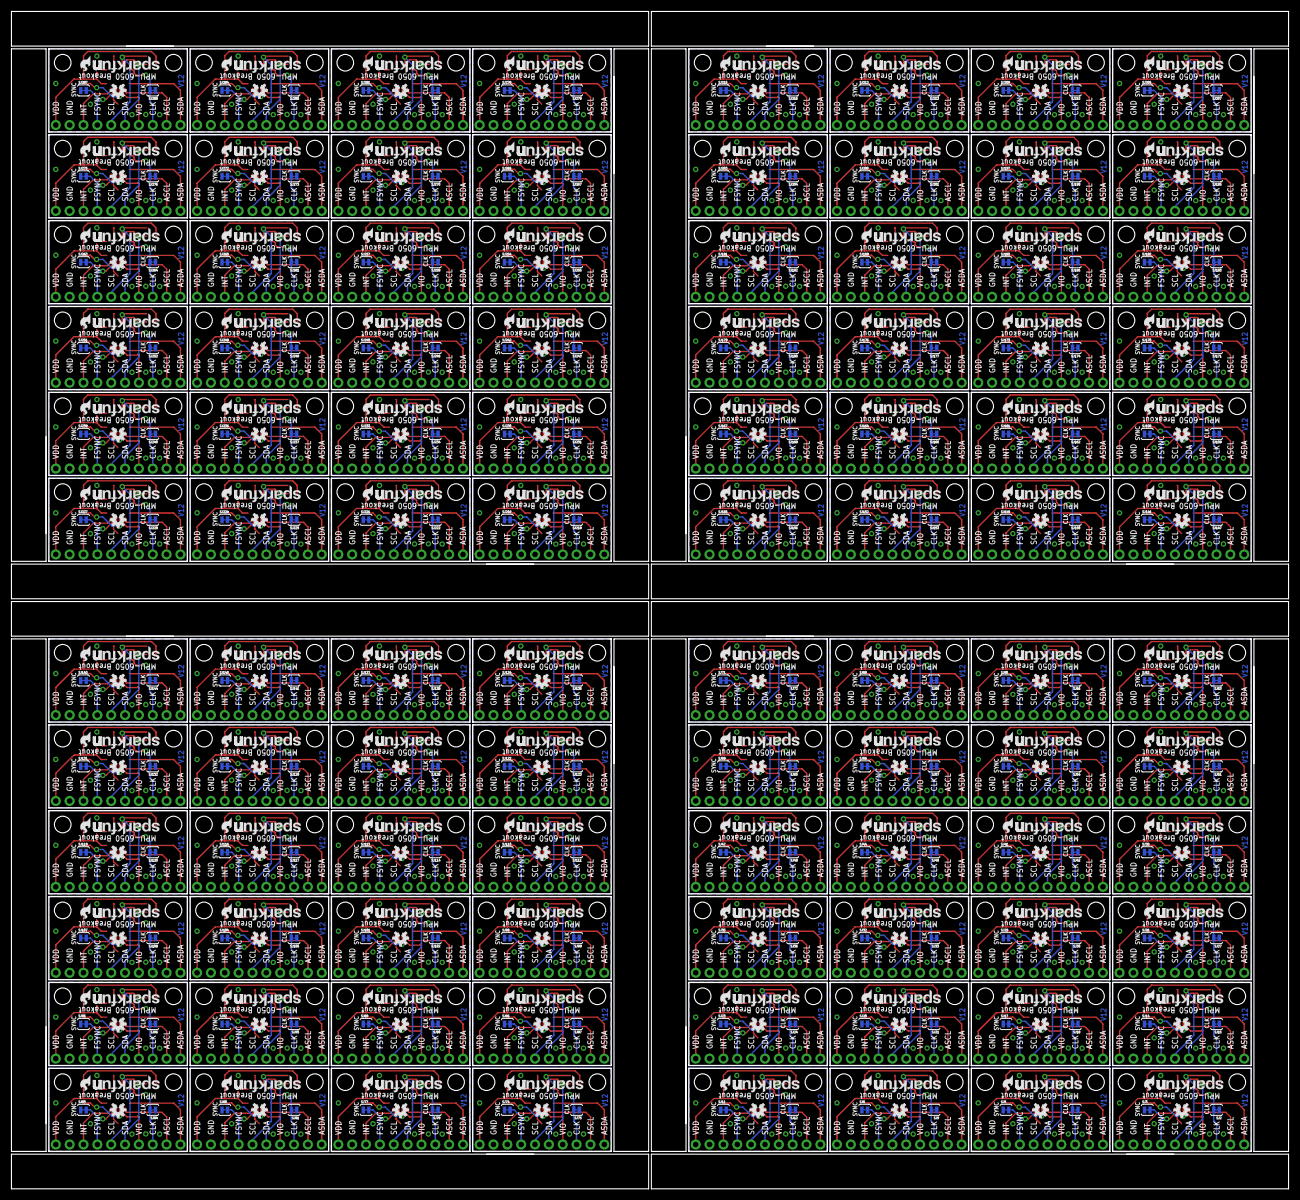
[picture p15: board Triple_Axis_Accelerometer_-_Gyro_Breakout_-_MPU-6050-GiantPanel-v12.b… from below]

Board: 2 copper layers, 234.2 x 215.9 mm, 1836 parts (480 on the bottom side), 1248 nets.

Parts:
C1, C3, C5, C7, C9, C11, C13, C15, C17, C19, C21, C23, C25, C27, C29, C31, C33, C35, C37, C39, C41, C43, C45, C47, C49, C51, C53, C55, C57, C59, C61, C63, C65, C67, C69, C71, C73, C75, C77, C79, C81, C83, C85, C87, C89, C91, C93, C95, C97, C99, C101, C103, C105, C107, C109, C111, C113, C115, C117, C119, C121, C123, C125, C127, C129, C131, C133, C135, C137, C139, C141, C143, C145, C147, C149, C151, C153, C155, C157, C159, C161, C163, C165, C167, C169, C171, C173, C175, C177, C179, C181, C183, C185, C187, C189, C191, C193, C195, C197, C199, C201, C203, C205, C207, C209, C211, C213, C215, C217, C219, C221, C223, C225, C227, C229, C231, C233, C235, C237, C239, C241, C243, C245, C247, C249, C251, C253, C255, C257, C259, C261, C263, C265, C267, C269, C271, C273, C275, C277, C279, C281, C283, C285, C287, C289, C291, C293, C295, C297, C299, C301, C303, C305, C307, C309, C311, C313, C315, C317, C319, C321, C323, C325, C327, C329, C331, C333, C335, C337, C339, C341, C343, C345, C347, C349, C351, C353, C355, C357, C359, C361, C363, C365, C367, C369, C371, C373, C375, C377, C379, C381, C383: 0.1uF; 0603-CAP
C2, C6, C10, C14, C18, C22, C26, C30, C34, C38, C42, C46, C50, C54, C58, C62, C66, C70, C74, C78, C82, C86, C90, C94, C98, C102, C106, C110, C114, C118, C122, C126, C130, C134, C138, C142, C146, C150, C154, C158, C162, C166, C170, C174, C178, C182, C186, C190, C194, C198, C202, C206, C210, C214, C218, C222, C226, C230, C234, C238, C242, C246, C250, C254, C258, C262, C266, C270, C274, C278, C282, C286, C290, C294, C298, C302, C306, C310, C314, C318, C322, C326, C330, C334, C338, C342, C346, C350, C354, C358, C362, C366, C370, C374, C378, C382: 2.2nF; 0603-CAP
C4, C8, C12, C16, C20, C24, C28, C32, C36, C40, C44, C48, C52, C56, C60, C64, C68, C72, C76, C80, C84, C88, C92, C96, C100, C104, C108, C112, C116, C120, C124, C128, C132, C136, C140, C144, C148, C152, C156, C160, C164, C168, C172, C176, C180, C184, C188, C192, C196, C200, C204, C208, C212, C216, C220, C224, C228, C232, C236, C240, C244, C248, C252, C256, C260, C264, C268, C272, C276, C280, C284, C288, C292, C296, C300, C304, C308, C312, C316, C320, C324, C328, C332, C336, C340, C344, C348, C352, C356, C360, C364, C368, C372, C376, C380, C384: 10nF; 0603-CAP
E$1, E$6, E$9, E$12: FIDUCIAL-1.5X3
E$2, E$3, E$4, E$5, E$7, E$8, E$10, E$11: FIDUCIAL-1X2
JP1, JP3, JP4, JP7, JP11, JP12, JP16, JP17, JP21, JP22, JP26, JP27, JP31, JP32, JP36, JP37, JP41, JP42, JP46, JP47, JP51, JP52, JP56, JP57, JP61, JP62, JP66, JP67, JP71, JP72, JP76, JP77, JP81, JP82, JP86, JP87, JP91, JP92, JP96, JP97, JP101, JP102, JP106, JP107, JP111, JP112, JP116, JP117, JP121, JP122, JP126, JP127, JP131, JP132, JP136, JP137, JP141, JP142, JP146, JP147, JP151, JP152, JP156, JP157, JP161, JP162, JP166, JP167, JP171, JP172, JP176, JP177, JP181, JP182, JP186, JP187, JP191, JP192, JP196, JP197, JP201, JP202, JP206, JP207, JP211, JP212, JP216, JP217, JP221, JP222, JP226, JP227, JP231, JP232, JP236, JP237, JP241, JP242, JP246, JP247, JP251, JP252, JP256, JP257, JP261, JP262, JP266, JP267, JP271, JP272, JP276, JP277, JP281, JP282, JP286, JP287, JP291, JP292, JP296, JP297, JP301, JP302, JP306, JP307, JP311, JP312, JP316, JP317, JP321, JP322, JP326, JP327, JP331, JP332, JP336, JP337, JP341, JP342, JP346, JP347, JP351, JP352, JP356, JP357, JP361, JP362, JP366, JP367, JP371, JP372, JP376, JP377, JP381, JP382, JP386, JP387, JP391, JP392, JP396, JP397, JP401, JP402, JP406, JP407, JP411, JP412, JP416, JP417, JP421, JP422, JP426, JP427, JP431, JP432, JP436, JP437, JP441, JP442, JP446, JP447, JP451, JP452, JP456, JP457, JP461, JP462, JP466, JP467, JP471, JP472, JP476, JP477: STAND-OFFTIGHT; STAND-OFF-TIGHT
JP2, JP5, JP8, JP9, JP13, JP14, JP18, JP19, JP23, JP24, JP28, JP29, JP33, JP34, JP38, JP39, JP43, JP44, JP48, JP49, JP53, JP54, JP58, JP59, JP63, JP64, JP68, JP69, JP73, JP74, JP78, JP79, JP83, JP84, JP88, JP89, JP93, JP94, JP98, JP99, JP103, JP104, JP108, JP109, JP113, JP114, JP118, JP119, JP123, JP124, JP128, JP129, JP133, JP134, JP138, JP139, JP143, JP144, JP148, JP149, JP153, JP154, JP158, JP159, JP163, JP164, JP168, JP169, JP173, JP174, JP178, JP179, JP183, JP184, JP188, JP189, JP193, JP194, JP198, JP199, JP203, JP204, JP208, JP209, JP213, JP214, JP218, JP219, JP223, JP224, JP228, JP229, JP233, JP234, JP238, JP239, JP243, JP244, JP248, JP249, JP253, JP254, JP258, JP259, JP263, JP264, JP268, JP269, JP273, JP274, JP278, JP279, JP283, JP284, JP288, JP289, JP293, JP294, JP298, JP299, JP303, JP304, JP308, JP309, JP313, JP314, JP318, JP319, JP323, JP324, JP328, JP329, JP333, JP334, JP338, JP339, JP343, JP344, JP348, JP349, JP353, JP354, JP358, JP359, JP363, JP364, JP368, JP369, JP373, JP374, JP378, JP379, JP383, JP384, JP388, JP389, JP393, JP394, JP398, JP399, JP403, JP404, JP408, JP409, JP413, JP414, JP418, JP419, JP423, JP424, JP428, JP429, JP433, JP434, JP438, JP439, JP443, JP444, JP448, JP449, JP453, JP454, JP458, JP459, JP463, JP464, JP468, JP469, JP473, JP474, JP478, JP479: FIDUCIALUFIDUCIAL; MICRO-FIDUCIAL
JP6, JP10, JP15, JP20, JP25, JP30, JP35, JP40, JP45, JP50, JP55, JP60, JP65, JP70, JP75, JP80, JP85, JP90, JP95, JP100, JP105, JP110, JP115, JP120, JP125, JP130, JP135, JP140, JP145, JP150, JP155, JP160, JP165, JP170, JP175, JP180, JP185, JP190, JP195, JP200, JP205, JP210, JP215, JP220, JP225, JP230, JP235, JP240, JP245, JP250, JP255, JP260, JP265, JP270, JP275, JP280, JP285, JP290, JP295, JP300, JP305, JP310, JP315, JP320, JP325, JP330, JP335, JP340, JP345, JP350, JP355, JP360, JP365, JP370, JP375, JP380, JP385, JP390, JP395, JP400, JP405, JP410, JP415, JP420, JP425, JP430, JP435, JP440, JP445, JP450, JP455, JP460, JP465, JP470, JP475, JP480: M10"; 1X10
R1, R2, R3, R4, R5, R6, R7, R8, R9, R10, R11, R12, R13, R14, R15, R16, R17, R18, R19, R20, R21, R22, R23, R24, R25, R26, R27, R28, R29, R30, R31, R32, R33, R34, R35, R36, R37, R38, R39, R40, R41, R42, R43, R44, R45, R46, R47, R48, R49, R50, R51, R52, R53, R54, R55, R56, R57, R58, R59, R60, R61, R62, R63, R64, R65, R66, R67, R68, R69, R70, R71, R72, R73, R74, R75, R76, R77, R78, R79, R80, R81, R82, R83, R84, R85, R86, R87, R88, R89, R90, R91, R92, R93, R94, R95, R96, R97, R98, R99, R100, R101, R102, R103, R104, R105, R106, R107, R108, R109, R110, R111, R112, R113, R114, R115, R116, R117, R118, R119, R120, R121, R122, R123, R124, R125, R126, R127, R128, R129, R130, R131, R132, R133, R134, R135, R136, R137, R138, R139, R140, R141, R142, R143, R144, R145, R146, R147, R148, R149, R150, R151, R152, R153, R154, R155, R156, R157, R158, R159, R160, R161, R162, R163, R164, R165, R166, R167, R168, R169, R170, R171, R172, R173, R174, R175, R176, R177, R178, R179, R180, R181, R182, R183, R184, R185, R186, R187, R188, R189, R190, R191, R192: 10k; 0603-RES
SJ1, SJ4, SJ7, SJ10, SJ13, SJ16, SJ19, SJ22, SJ25, SJ28, SJ31, SJ34, SJ37, SJ40, SJ43, SJ46, SJ49, SJ52, SJ55, SJ58, SJ61, SJ64, SJ67, SJ70, SJ73, SJ76, SJ79, SJ82, SJ85, SJ88, SJ91, SJ94, SJ97, SJ100, SJ103, SJ106, SJ109, SJ112, SJ115, SJ118, SJ121, SJ124, SJ127, SJ130, SJ133, SJ136, SJ139, SJ142, SJ145, SJ148, SJ151, SJ154, SJ157, SJ160, SJ163, SJ166, SJ169, SJ172, SJ175, SJ178, SJ181, SJ184, SJ187, SJ190, SJ193, SJ196, SJ199, SJ202, SJ205, SJ208, SJ211, SJ214, SJ217, SJ220, SJ223, SJ226, SJ229, SJ232, SJ235, SJ238, SJ241, SJ244, SJ247, SJ250, SJ253, SJ256, SJ259, SJ262, SJ265, SJ268, SJ271, SJ274, SJ277, SJ280, SJ283, SJ286: SJ_3_PASTE2&3
SJ2, SJ3, SJ5, SJ6, SJ8, SJ9, SJ11, SJ12, SJ14, SJ15, SJ17, SJ18, SJ20, SJ21, SJ23, SJ24, SJ26, SJ27, SJ29, SJ30, SJ32, SJ33, SJ35, SJ36, SJ38, SJ39, SJ41, SJ42, SJ44, SJ45, SJ47, SJ48, SJ50, SJ51, SJ53, SJ54, SJ56, SJ57, SJ59, SJ60, SJ62, SJ63, SJ65, SJ66, SJ68, SJ69, SJ71, SJ72, SJ74, SJ75, SJ77, SJ78, SJ80, SJ81, SJ83, SJ84, SJ86, SJ87, SJ89, SJ90, SJ92, SJ93, SJ95, SJ96, SJ98, SJ99, SJ101, SJ102, SJ104, SJ105, SJ107, SJ108, SJ110, SJ111, SJ113, SJ114, SJ116, SJ117, SJ119, SJ120, SJ122, SJ123, SJ125, SJ126, SJ128, SJ129, SJ131, SJ132, SJ134, SJ135, SJ137, SJ138, SJ140, SJ141, SJ143, SJ144, SJ146, SJ147, SJ149, SJ150, SJ152, SJ153, SJ155, SJ156, SJ158, SJ159, SJ161, SJ162, SJ164, SJ165, SJ167, SJ168, SJ170, SJ171, SJ173, SJ174, SJ176, SJ177, SJ179, SJ180, SJ182, SJ183, SJ185, SJ186, SJ188, SJ189, SJ191, SJ192, SJ194, SJ195, SJ197, SJ198, SJ200, SJ201, SJ203, SJ204, SJ206, SJ207, SJ209, SJ210, SJ212, SJ213, SJ215, SJ216, SJ218, SJ219, SJ221, SJ222, SJ224, SJ225, SJ227, SJ228, SJ230, SJ231, SJ233, SJ234, SJ236, SJ237, SJ239, SJ240, SJ242, SJ243, SJ245, SJ246, SJ248, SJ249, SJ251, SJ252, SJ254, SJ255, SJ257, SJ258, SJ260, SJ261, SJ263, SJ264, SJ266, SJ267, SJ269, SJ270, SJ272, SJ273, SJ275, SJ276, SJ278, SJ279, SJ281, SJ282, SJ284, SJ285, SJ287, SJ288: SJ_2S-TRACE
U1, U2, U3, U4, U5, U6, U7, U8, U9, U10, U11, U12, U13, U14, U15, U16, U17, U18, U19, U20, U21, U22, U23, U24, U25, U26, U27, U28, U29, U30, U31, U32, U33, U34, U35, U36, U37, U38, U39, U40, U41, U42, U43, U44, U45, U46, U47, U48, U49, U50, U51, U52, U53, U54, U55, U56, U57, U58, U59, U60, U61, U62, U63, U64, U65, U66, U67, U68, U69, U70, U71, U72, U73, U74, U75, U76, U77, U78, U79, U80, U81, U82, U83, U84, U85, U86, U87, U88, U89, U90, U91, U92, U93, U94, U95, U96: MPU-6050-1; QFN-24-4MM2
U$1, U$6, U$10, U$14, U$18, U$22, U$26, U$30, U$34, U$38, U$42, U$46, U$50, U$54, U$58, U$62, U$66, U$70, U$74, U$78, U$82, U$86, U$90, U$94, U$98, U$102, U$106, U$110, U$114, U$118, U$122, U$126, U$130, U$134, U$138, U$142, U$146, U$150, U$154, U$158, U$162, U$166, U$170, U$174, U$178, U$182, U$186, U$190, U$194, U$198, U$202, U$206, U$210, U$214, U$218, U$222, U$226, U$230, U$234, U$238, U$242, U$246, U$250, U$254, U$258, U$262, U$266, U$270, U$274, U$278, U$282, U$286, U$290, U$294, U$298, U$302, U$306, U$310, U$314, U$318, U$322, U$326, U$330, U$334, U$338, U$342, U$346, U$350, U$354, U$358, U$362, U$366, U$370, U$374, U$378, U$382: OSHW-LOGOS; OSHW-LOGO-S
U$2, U$3, U$5, U$7, U$9, U$11, U$13, U$15, U$17, U$19, U$21, U$23, U$25, U$27, U$29, U$31, U$33, U$35, U$37, U$39, U$41, U$43, U$45, U$47, U$49, U$51, U$53, U$55, U$57, U$59, U$61, U$63, U$65, U$67, U$69, U$71, U$73, U$75, U$77, U$79, U$81, U$83, U$85, U$87, U$89, U$91, U$93, U$95, U$97, U$99, U$101, U$103, U$105, U$107, U$109, U$111, U$113, U$115, U$117, U$119, U$121, U$123, U$125, U$127, U$129, U$131, U$133, U$135, U$137, U$139, U$141, U$143, U$145, U$147, U$149, U$151, U$153, U$155, U$157, U$159, U$161, U$163, U$165, U$167, U$169, U$171, U$173, U$175, U$177, U$179, U$181, U$183, U$185, U$187, U$189, U$191, U$193, U$195, U$197, U$199, U$201, U$203, U$205, U$207, U$209, U$211, U$213, U$215, U$217, U$219, U$221, U$223, U$225, U$227, U$229, U$231, U$233, U$235, U$237, U$239, U$241, U$243, U$245, U$247, U$249, U$251, U$253, U$255, U$257, U$259, U$261, U$263, U$265, U$267, U$269, U$271, U$273, U$275, U$277, U$279, U$281, U$283, U$285, U$287, U$289, U$291, U$293, U$295, U$297, U$299, U$301, U$303, U$305, U$307, U$309, U$311, U$313, U$315, U$317, U$319, U$321, U$323, U$325, U$327, U$329, U$331, U$333, U$335, U$337, U$339, U$341, U$343, U$345, U$347, U$349, U$351, U$353, U$355, U$357, U$359, U$361, U$363, U$365, U$367, U$369, U$371, U$373, U$375, U$377, U$379, U$381, U$383: SFE-LOGO-FLAME
U$4, U$8, U$12, U$16, U$20, U$24, U$28, U$32, U$36, U$40, U$44, U$48, U$52, U$56, U$60, U$64, U$68, U$72, U$76, U$80, U$84, U$88, U$92, U$96, U$100, U$104, U$108, U$112, U$116, U$120, U$124, U$128, U$132, U$136, U$140, U$144, U$148, U$152, U$156, U$160, U$164, U$168, U$172, U$176, U$180, U$184, U$188, U$192, U$196, U$200, U$204, U$208, U$212, U$216, U$220, U$224, U$228, U$232, U$236, U$240, U$244, U$248, U$252, U$256, U$260, U$264, U$268, U$272, U$276, U$280, U$284, U$288, U$292, U$296, U$300, U$304, U$308, U$312, U$316, U$320, U$324, U$328, U$332, U$336, U$340, U$344, U$348, U$352, U$356, U$360, U$364, U$368, U$372, U$376, U$380, U$384: SFE-NEW-WEB

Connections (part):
ADO: SJ1.2, U1.9
ADO1: SJ4.2, U2.9
ADO2: SJ7.2, U3.9
ADO3: SJ10.2, U4.9
ADO4: SJ13.2, U5.9
ADO5: SJ16.2, U6.9
ADO6: SJ19.2, U7.9
ADO7: SJ22.2, U8.9
ADO8: SJ25.2, U9.9
ADO9: SJ28.2, U10.9
ADO10: SJ31.2, U11.9
ADO11: SJ34.2, U12.9
ADO12: SJ37.2, U13.9
ADO13: SJ40.2, U14.9
ADO14: SJ43.2, U15.9
ADO15: SJ46.2, U16.9
ADO16: SJ49.2, U17.9
ADO17: SJ52.2, U18.9
ADO18: SJ55.2, U19.9
ADO19: SJ58.2, U20.9
ADO20: SJ61.2, U21.9
ADO21: SJ64.2, U22.9
ADO22: SJ67.2, U23.9
ADO23: SJ70.2, U24.9
ADO24: SJ73.2, U25.9
ADO25: SJ76.2, U26.9
ADO26: SJ79.2, U27.9
ADO27: SJ82.2, U28.9
ADO28: SJ85.2, U29.9
ADO29: SJ88.2, U30.9
ADO30: SJ91.2, U31.9
ADO31: SJ94.2, U32.9
ADO32: SJ97.2, U33.9
ADO33: SJ100.2, U34.9
ADO34: SJ103.2, U35.9
ADO35: SJ106.2, U36.9
ADO36: SJ109.2, U37.9
ADO37: SJ112.2, U38.9
ADO38: SJ115.2, U39.9
ADO39: SJ118.2, U40.9
ADO40: SJ121.2, U41.9
ADO41: SJ124.2, U42.9
ADO42: SJ127.2, U43.9
ADO43: SJ130.2, U44.9
ADO44: SJ133.2, U45.9
ADO45: SJ136.2, U46.9
ADO46: SJ139.2, U47.9
ADO47: SJ142.2, U48.9
ADO48: SJ145.2, U49.9
ADO49: SJ148.2, U50.9
ADO50: SJ151.2, U51.9
ADO51: SJ154.2, U52.9
ADO52: SJ157.2, U53.9
ADO53: SJ160.2, U54.9
ADO54: SJ163.2, U55.9
ADO55: SJ166.2, U56.9
ADO56: SJ169.2, U57.9
ADO57: SJ172.2, U58.9
ADO58: SJ175.2, U59.9
ADO59: SJ178.2, U60.9
ADO60: SJ181.2, U61.9
ADO61: SJ184.2, U62.9
ADO62: SJ187.2, U63.9
ADO63: SJ190.2, U64.9
ADO64: SJ193.2, U65.9
ADO65: SJ196.2, U66.9
ADO66: SJ199.2, U67.9
ADO67: SJ202.2, U68.9
ADO68: SJ205.2, U69.9
ADO69: SJ208.2, U70.9
ADO70: SJ211.2, U71.9
ADO71: SJ214.2, U72.9
ADO72: SJ217.2, U73.9
ADO73: SJ220.2, U74.9
ADO74: SJ223.2, U75.9
ADO75: SJ226.2, U76.9
ADO76: SJ229.2, U77.9
ADO77: SJ232.2, U78.9
ADO78: SJ235.2, U79.9
ADO79: SJ238.2, U80.9
ADO80: SJ241.2, U81.9
ADO81: SJ244.2, U82.9
ADO82: SJ247.2, U83.9
ADO83: SJ250.2, U84.9
ADO84: SJ253.2, U85.9
ADO85: SJ256.2, U86.9
ADO86: SJ259.2, U87.9
ADO87: SJ262.2, U88.9
ADO88: SJ265.2, U89.9
ADO89: SJ268.2, U90.9
ADO90: SJ271.2, U91.9
ADO91: SJ274.2, U92.9
ADO92: SJ277.2, U93.9
ADO93: SJ280.2, U94.9
ADO94: SJ283.2, U95.9
ADO95: SJ286.2, U96.9
AUX_SCL: JP6.2, U1.7
AUX_SCL1: JP10.2, U2.7
AUX_SCL2: JP15.2, U3.7
AUX_SCL3: JP20.2, U4.7
AUX_SCL4: JP25.2, U5.7
AUX_SCL5: JP30.2, U6.7
AUX_SCL6: JP35.2, U7.7
AUX_SCL7: JP40.2, U8.7
AUX_SCL8: JP45.2, U9.7
AUX_SCL9: JP50.2, U10.7
AUX_SCL10: JP55.2, U11.7
AUX_SCL11: JP60.2, U12.7
AUX_SCL12: JP65.2, U13.7
AUX_SCL13: JP70.2, U14.7
AUX_SCL14: JP75.2, U15.7
AUX_SCL15: JP80.2, U16.7
AUX_SCL16: JP85.2, U17.7
AUX_SCL17: JP90.2, U18.7
AUX_SCL18: JP95.2, U19.7
AUX_SCL19: JP100.2, U20.7
AUX_SCL20: JP105.2, U21.7
AUX_SCL21: JP110.2, U22.7
AUX_SCL22: JP115.2, U23.7
AUX_SCL23: JP120.2, U24.7
AUX_SCL24: JP125.2, U25.7
AUX_SCL25: JP130.2, U26.7
AUX_SCL26: JP135.2, U27.7
AUX_SCL27: JP140.2, U28.7
AUX_SCL28: JP145.2, U29.7
AUX_SCL29: JP150.2, U30.7
AUX_SCL30: JP155.2, U31.7
AUX_SCL31: JP160.2, U32.7
AUX_SCL32: JP165.2, U33.7
AUX_SCL33: JP170.2, U34.7
AUX_SCL34: JP175.2, U35.7
AUX_SCL35: JP180.2, U36.7
AUX_SCL36: JP185.2, U37.7
AUX_SCL37: JP190.2, U38.7
AUX_SCL38: JP195.2, U39.7
AUX_SCL39: JP200.2, U40.7
AUX_SCL40: JP205.2, U41.7
AUX_SCL41: JP210.2, U42.7
AUX_SCL42: JP215.2, U43.7
AUX_SCL43: JP220.2, U44.7
AUX_SCL44: JP225.2, U45.7
AUX_SCL45: JP230.2, U46.7
AUX_SCL46: JP235.2, U47.7
AUX_SCL47: JP240.2, U48.7
AUX_SCL48: JP245.2, U49.7
AUX_SCL49: JP250.2, U50.7
AUX_SCL50: JP255.2, U51.7
AUX_SCL51: JP260.2, U52.7
AUX_SCL52: JP265.2, U53.7
AUX_SCL53: JP270.2, U54.7
AUX_SCL54: JP275.2, U55.7
AUX_SCL55: JP280.2, U56.7
AUX_SCL56: JP285.2, U57.7
AUX_SCL57: JP290.2, U58.7
AUX_SCL58: JP295.2, U59.7
AUX_SCL59: JP300.2, U60.7
AUX_SCL60: JP305.2, U61.7
AUX_SCL61: JP310.2, U62.7
AUX_SCL62: JP315.2, U63.7
AUX_SCL63: JP320.2, U64.7
AUX_SCL64: JP325.2, U65.7
AUX_SCL65: JP330.2, U66.7
AUX_SCL66: JP335.2, U67.7
AUX_SCL67: JP340.2, U68.7
AUX_SCL68: JP345.2, U69.7
AUX_SCL69: JP350.2, U70.7
AUX_SCL70: JP355.2, U71.7
AUX_SCL71: JP360.2, U72.7
AUX_SCL72: JP365.2, U73.7
AUX_SCL73: JP370.2, U74.7
AUX_SCL74: JP375.2, U75.7
AUX_SCL75: JP380.2, U76.7
AUX_SCL76: JP385.2, U77.7
AUX_SCL77: JP390.2, U78.7
AUX_SCL78: JP395.2, U79.7
AUX_SCL79: JP400.2, U80.7
AUX_SCL80: JP405.2, U81.7
AUX_SCL81: JP410.2, U82.7
AUX_SCL82: JP415.2, U83.7
AUX_SCL83: JP420.2, U84.7
AUX_SCL84: JP425.2, U85.7
AUX_SCL85: JP430.2, U86.7
AUX_SCL86: JP435.2, U87.7
AUX_SCL87: JP440.2, U88.7
AUX_SCL88: JP445.2, U89.7
AUX_SCL89: JP450.2, U90.7
AUX_SCL90: JP455.2, U91.7
AUX_SCL91: JP460.2, U92.7
AUX_SCL92: JP465.2, U93.7
AUX_SCL93: JP470.2, U94.7
AUX_SCL94: JP475.2, U95.7
AUX_SCL95: JP480.2, U96.7
AUX_SDA: JP6.1, U1.6
AUX_SDA1: JP10.1, U2.6
AUX_SDA2: JP15.1, U3.6
AUX_SDA3: JP20.1, U4.6
AUX_SDA4: JP25.1, U5.6
AUX_SDA5: JP30.1, U6.6
AUX_SDA6: JP35.1, U7.6
AUX_SDA7: JP40.1, U8.6
AUX_SDA8: JP45.1, U9.6
AUX_SDA9: JP50.1, U10.6
AUX_SDA10: JP55.1, U11.6
AUX_SDA11: JP60.1, U12.6
AUX_SDA12: JP65.1, U13.6
AUX_SDA13: JP70.1, U14.6
AUX_SDA14: JP75.1, U15.6
AUX_SDA15: JP80.1, U16.6
AUX_SDA16: JP85.1, U17.6
AUX_SDA17: JP90.1, U18.6
AUX_SDA18: JP95.1, U19.6
AUX_SDA19: JP100.1, U20.6
AUX_SDA20: JP105.1, U21.6
AUX_SDA21: JP110.1, U22.6
AUX_SDA22: JP115.1, U23.6
AUX_SDA23: JP120.1, U24.6
AUX_SDA24: JP125.1, U25.6
AUX_SDA25: JP130.1, U26.6
AUX_SDA26: JP135.1, U27.6
AUX_SDA27: JP140.1, U28.6
AUX_SDA28: JP145.1, U29.6
AUX_SDA29: JP150.1, U30.6
AUX_SDA30: JP155.1, U31.6
AUX_SDA31: JP160.1, U32.6
AUX_SDA32: JP165.1, U33.6
AUX_SDA33: JP170.1, U34.6
AUX_SDA34: JP175.1, U35.6
AUX_SDA35: JP180.1, U36.6
AUX_SDA36: JP185.1, U37.6
AUX_SDA37: JP190.1, U38.6
AUX_SDA38: JP195.1, U39.6
AUX_SDA39: JP200.1, U40.6
AUX_SDA40: JP205.1, U41.6
AUX_SDA41: JP210.1, U42.6
AUX_SDA42: JP215.1, U43.6
AUX_SDA43: JP220.1, U44.6
AUX_SDA44: JP225.1, U45.6
AUX_SDA45: JP230.1, U46.6
AUX_SDA46: JP235.1, U47.6
AUX_SDA47: JP240.1, U48.6
AUX_SDA48: JP245.1, U49.6
AUX_SDA49: JP250.1, U50.6
AUX_SDA50: JP255.1, U51.6
AUX_SDA51: JP260.1, U52.6
AUX_SDA52: JP265.1, U53.6
AUX_SDA53: JP270.1, U54.6
AUX_SDA54: JP275.1, U55.6
AUX_SDA55: JP280.1, U56.6
AUX_SDA56: JP285.1, U57.6
AUX_SDA57: JP290.1, U58.6
AUX_SDA58: JP295.1, U59.6
AUX_SDA59: JP300.1, U60.6
AUX_SDA60: JP305.1, U61.6
AUX_SDA61: JP310.1, U62.6
AUX_SDA62: JP315.1, U63.6
AUX_SDA63: JP320.1, U64.6
AUX_SDA64: JP325.1, U65.6
AUX_SDA65: JP330.1, U66.6
AUX_SDA66: JP335.1, U67.6
AUX_SDA67: JP340.1, U68.6
AUX_SDA68: JP345.1, U69.6
AUX_SDA69: JP350.1, U70.6
AUX_SDA70: JP355.1, U71.6
AUX_SDA71: JP360.1, U72.6
AUX_SDA72: JP365.1, U73.6
AUX_SDA73: JP370.1, U74.6
AUX_SDA74: JP375.1, U75.6
AUX_SDA75: JP380.1, U76.6
AUX_SDA76: JP385.1, U77.6
AUX_SDA77: JP390.1, U78.6
AUX_SDA78: JP395.1, U79.6
AUX_SDA79: JP400.1, U80.6
AUX_SDA80: JP405.1, U81.6
AUX_SDA81: JP410.1, U82.6
AUX_SDA82: JP415.1, U83.6
AUX_SDA83: JP420.1, U84.6
AUX_SDA84: JP425.1, U85.6
AUX_SDA85: JP430.1, U86.6
AUX_SDA86: JP435.1, U87.6
AUX_SDA87: JP440.1, U88.6
AUX_SDA88: JP445.1, U89.6
AUX_SDA89: JP450.1, U90.6
AUX_SDA90: JP455.1, U91.6
AUX_SDA91: JP460.1, U92.6
AUX_SDA92: JP465.1, U93.6
AUX_SDA93: JP470.1, U94.6
AUX_SDA94: JP475.1, U95.6
AUX_SDA95: JP480.1, U96.6
CLKIN: JP6.3, SJ2.2, U1.1
CLKIN1: JP10.3, SJ6.2, U2.1
CLKIN2: JP15.3, SJ9.2, U3.1
CLKIN3: JP20.3, SJ12.2, U4.1
CLKIN4: JP25.3, SJ15.2, U5.1
CLKIN5: JP30.3, SJ18.2, U6.1
CLKIN6: JP35.3, SJ21.2, U7.1
CLKIN7: JP40.3, SJ24.2, U8.1
CLKIN8: JP45.3, SJ27.2, U9.1
CLKIN9: JP50.3, SJ30.2, U10.1
CLKIN10: JP55.3, SJ33.2, U11.1
CLKIN11: JP60.3, SJ36.2, U12.1
CLKIN12: JP65.3, SJ39.2, U13.1
CLKIN13: JP70.3, SJ42.2, U14.1
CLKIN14: JP75.3, SJ45.2, U15.1
CLKIN15: JP80.3, SJ48.2, U16.1
CLKIN16: JP85.3, SJ51.2, U17.1
CLKIN17: JP90.3, SJ54.2, U18.1
CLKIN18: JP95.3, SJ57.2, U19.1
CLKIN19: JP100.3, SJ60.2, U20.1
CLKIN20: JP105.3, SJ63.2, U21.1
CLKIN21: JP110.3, SJ66.2, U22.1
CLKIN22: JP115.3, SJ69.2, U23.1
CLKIN23: JP120.3, SJ72.2, U24.1
CLKIN24: JP125.3, SJ75.2, U25.1
CLKIN25: JP130.3, SJ78.2, U26.1
CLKIN26: JP135.3, SJ81.2, U27.1
CLKIN27: JP140.3, SJ84.2, U28.1
CLKIN28: JP145.3, SJ87.2, U29.1
CLKIN29: JP150.3, SJ90.2, U30.1
CLKIN30: JP155.3, SJ93.2, U31.1
CLKIN31: JP160.3, SJ96.2, U32.1
CLKIN32: JP165.3, SJ99.2, U33.1
CLKIN33: JP170.3, SJ102.2, U34.1
CLKIN34: JP175.3, SJ105.2, U35.1
CLKIN35: JP180.3, SJ108.2, U36.1
CLKIN36: JP185.3, SJ111.2, U37.1
CLKIN37: JP190.3, SJ114.2, U38.1
CLKIN38: JP195.3, SJ117.2, U39.1
CLKIN39: JP200.3, SJ120.2, U40.1
CLKIN40: JP205.3, SJ123.2, U41.1
CLKIN41: JP210.3, SJ126.2, U42.1
CLKIN42: JP215.3, SJ129.2, U43.1
CLKIN43: JP220.3, SJ132.2, U44.1
CLKIN44: JP225.3, SJ135.2, U45.1
CLKIN45: JP230.3, SJ138.2, U46.1
CLKIN46: JP235.3, SJ141.2, U47.1
CLKIN47: JP240.3, SJ144.2, U48.1
CLKIN48: JP245.3, SJ147.2, U49.1
CLKIN49: JP250.3, SJ150.2, U50.1
CLKIN50: JP255.3, SJ153.2, U51.1
CLKIN51: JP260.3, SJ156.2, U52.1
CLKIN52: JP265.3, SJ159.2, U53.1
CLKIN53: JP270.3, SJ162.2, U54.1
CLKIN54: JP275.3, SJ165.2, U55.1
CLKIN55: JP280.3, SJ168.2, U56.1
CLKIN56: JP285.3, SJ171.2, U57.1
CLKIN57: JP290.3, SJ174.2, U58.1
CLKIN58: JP295.3, SJ177.2, U59.1
CLKIN59: JP300.3, SJ180.2, U60.1
CLKIN60: JP305.3, SJ183.2, U61.1
CLKIN61: JP310.3, SJ186.2, U62.1
CLKIN62: JP315.3, SJ189.2, U63.1
CLKIN63: JP320.3, SJ192.2, U64.1
CLKIN64: JP325.3, SJ195.2, U65.1
CLKIN65: JP330.3, SJ198.2, U66.1
CLKIN66: JP335.3, SJ201.2, U67.1
CLKIN67: JP340.3, SJ204.2, U68.1
CLKIN68: JP345.3, SJ207.2, U69.1
CLKIN69: JP350.3, SJ210.2, U70.1
CLKIN70: JP355.3, SJ213.2, U71.1
CLKIN71: JP360.3, SJ216.2, U72.1
CLKIN72: JP365.3, SJ219.2, U73.1
CLKIN73: JP370.3, SJ222.2, U74.1
CLKIN74: JP375.3, SJ225.2, U75.1
CLKIN75: JP380.3, SJ228.2, U76.1
CLKIN76: JP385.3, SJ231.2, U77.1
CLKIN77: JP390.3, SJ234.2, U78.1
CLKIN78: JP395.3, SJ237.2, U79.1
CLKIN79: JP400.3, SJ240.2, U80.1
CLKIN80: JP405.3, SJ243.2, U81.1
CLKIN81: JP410.3, SJ246.2, U82.1
CLKIN82: JP415.3, SJ249.2, U83.1
CLKIN83: JP420.3, SJ252.2, U84.1
CLKIN84: JP425.3, SJ255.2, U85.1
CLKIN85: JP430.3, SJ258.2, U86.1
CLKIN86: JP435.3, SJ261.2, U87.1
CLKIN87: JP440.3, SJ264.2, U88.1
CLKIN88: JP445.3, SJ267.2, U89.1
CLKIN89: JP450.3, SJ270.2, U90.1
CLKIN90: JP455.3, SJ273.2, U91.1
CLKIN91: JP460.3, SJ276.2, U92.1
CLKIN92: JP465.3, SJ279.2, U93.1
CLKIN93: JP470.3, SJ282.2, U94.1
CLKIN94: JP475.3, SJ285.2, U95.1
CLKIN95: JP480.3, SJ288.2, U96.1
FSYNC: JP6.7, SJ3.2, U1.11
FSYNC1: JP10.7, SJ5.2, U2.11
FSYNC2: JP15.7, SJ8.2, U3.11
FSYNC3: JP20.7, SJ11.2, U4.11
FSYNC4: JP25.7, SJ14.2, U5.11
FSYNC5: JP30.7, SJ17.2, U6.11
FSYNC6: JP35.7, SJ20.2, U7.11
FSYNC7: JP40.7, SJ23.2, U8.11
FSYNC8: JP45.7, SJ26.2, U9.11
FSYNC9: JP50.7, SJ29.2, U10.11
FSYNC10: JP55.7, SJ32.2, U11.11
FSYNC11: JP60.7, SJ35.2, U12.11
FSYNC12: JP65.7, SJ38.2, U13.11
FSYNC13: JP70.7, SJ41.2, U14.11
FSYNC14: JP75.7, SJ44.2, U15.11
FSYNC15: JP80.7, SJ47.2, U16.11
FSYNC16: JP85.7, SJ50.2, U17.11
FSYNC17: JP90.7, SJ53.2, U18.11
FSYNC18: JP95.7, SJ56.2, U19.11
FSYNC19: JP100.7, SJ59.2, U20.11
FSYNC20: JP105.7, SJ62.2, U21.11
FSYNC21: JP110.7, SJ65.2, U22.11
FSYNC22: JP115.7, SJ68.2, U23.11
FSYNC23: JP120.7, SJ71.2, U24.11
FSYNC24: JP125.7, SJ74.2, U25.11
FSYNC25: JP130.7, SJ77.2, U26.11
FSYNC26: JP135.7, SJ80.2, U27.11
FSYNC27: JP140.7, SJ83.2, U28.11
FSYNC28: JP145.7, SJ86.2, U29.11
FSYNC29: JP150.7, SJ89.2, U30.11
FSYNC30: JP155.7, SJ92.2, U31.11
FSYNC31: JP160.7, SJ95.2, U32.11
FSYNC32: JP165.7, SJ98.2, U33.11
FSYNC33: JP170.7, SJ101.2, U34.11
FSYNC34: JP175.7, SJ104.2, U35.11
FSYNC35: JP180.7, SJ107.2, U36.11
FSYNC36: JP185.7, SJ110.2, U37.11
FSYNC37: JP190.7, SJ113.2, U38.11
FSYNC38: JP195.7, SJ116.2, U39.11
FSYNC39: JP200.7, SJ119.2, U40.11
FSYNC40: JP205.7, SJ122.2, U41.11
FSYNC41: JP210.7, SJ125.2, U42.11
FSYNC42: JP215.7, SJ128.2, U43.11
FSYNC43: JP220.7, SJ131.2, U44.11
FSYNC44: JP225.7, SJ134.2, U45.11
FSYNC45: JP230.7, SJ137.2, U46.11
FSYNC46: JP235.7, SJ140.2, U47.11
FSYNC47: JP240.7, SJ143.2, U48.11
FSYNC48: JP245.7, SJ146.2, U49.11
FSYNC49: JP250.7, SJ149.2, U50.11
FSYNC50: JP255.7, SJ152.2, U51.11
FSYNC51: JP260.7, SJ155.2, U52.11
FSYNC52: JP265.7, SJ158.2, U53.11
FSYNC53: JP270.7, SJ161.2, U54.11
FSYNC54: JP275.7, SJ164.2, U55.11
FSYNC55: JP280.7, SJ167.2, U56.11
FSYNC56: JP285.7, SJ170.2, U57.11
FSYNC57: JP290.7, SJ173.2, U58.11
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

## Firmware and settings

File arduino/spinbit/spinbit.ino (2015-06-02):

// SpinBit
// Katie Kemp, Isaac Perry, Adam Ryman // // Documentation: // - The InvenSense documents: //   - "MPU-6000 and MPU-6050 Product Specification", //     PS-MPU-6000A.pdf //   - "MPU-6000 and MPU-6050 Register Map and Descriptions", //     RM-MPU-6000A.pdf or RS-MPU-6000A.pdf //   - "MPU-6000/MPU-6050 9-Axis Evaluation Board User Guide" //     AN-MPU-6000EVB.pdf // // The accuracy is 16-bits.  // // Temperature sensor from -40 to +85 degrees Celsius //   340 per degrees, -512 at 35 degrees.  // // At power-up, all registers are zero, except these two: //      Register 0x6B (PWR_MGMT_2) = 0x40  (I read zero).  //      Register 0x75 (WHO_AM_I)   = 0x68.  // // MPU-6050 Short Example Sketch // By Arduino User JohnChi // August 17, 2014 // Public Domain /*
  SD card datalogger

 This example shows how to log data from three analog sensors
 to an SD card using the SD library.

 The circuit:
 * analog sensors on analog ins 0, 1, and 2
 * SD card attached to SPI bus as follows:
 ** MOSI - pin 11
 ** MISO - pin 12
 ** CLK - pin 13
 ** CS - pin 10

 created  24 Nov 2010
 modified 9 Apr 2012
 by Tom Igoe

 This example code is in the public domain.

 */

//Includes

// WinBond flash commands
#define WB_WRITE_ENABLE       0x06
#define WB_WRITE_DISABLE      0x04
#define WB_CHIP_ERASE         0xc7
#define WB_READ_STATUS_REG_1  0x05
#define WB_READ_DATA          0x03
#define WB_PAGE_PROGRAM       0x02
#define WB_JEDEC_ID           0x9f

//Change this to 0 to have device switch controlled 1 to have it bluetooth controlled
#define BLUETOOTHCONTROLLED 1


#include <Wire.h>

#include <SPI.h>
#include <SD.h>

#include <SoftwareSerial.h>

#include "defines.h"

// Declaring an union for the registers and the axis values.
// The byte order does not match the byte order of
// the compiler and AVR chip.
// The AVR chip (on the Arduino board) has the Low Byte
// at the lower address.
// But the MPU-6050 has a different order: High Byte at
// lower address, so that has to be corrected.
// The register part "reg" is only used internally,
// and are swapped in code.
typedef union accel_t_gyro_union
{
  struct
  {
    uint8_t x_accel_h;
    uint8_t x_accel_l;
    uint8_t y_accel_h;
    uint8_t y_accel_l;
    uint8_t z_accel_h;
    uint8_t z_accel_l;
    uint8_t t_h;
    uint8_t t_l;
    uint8_t x_gyro_h;
    uint8_t x_gyro_l;
    uint8_t y_gyro_h;
    uint8_t y_gyro_l;
    uint8_t z_gyro_h;
    uint8_t z_gyro_l;
  }
  reg;
  struct
  {
    int16_t x_accel;
    int16_t y_accel;
    int16_t z_accel;
    int16_t temperature;
    int16_t x_gyro;
    int16_t y_gyro;
    int16_t z_gyro;
  }
  value;
};

const int sdChipSelectPin = 10;

const int writeSwitchPin = 7;
const int bluetoothSwitchPin = 6;
const int deleteSwitchPin = 5;
const int ledPin = 9;

const int buttonPin = 2;
int buttonState;
int lastButtonState = LOW;

long lastDebounceTime = 0;
long debounceDelay = 50;

int bluetoothSwitchState = 0;
boolean writeSwitchState = 0;
int deleteSwitchState = 0;

boolean writeBreak = false;

long lastSpin;
int bluetoothTx = 3;  // TX - TX
int bluetoothRx = 4;  // RX - RX

SoftwareSerial bluetooth(bluetoothTx, bluetoothRx);

int fileNumber = 0;

char currentFile[14];

void setup()
{
  //---------------------- General Setup -------------------------------//
  //vars for printing
  int error;
  uint8_t c;

  Serial.begin(9600);
  bluetooth.begin(9600);

  //------------------------------ Gyro Setup ---------------------------//
  Wire.begin();

  //Check WHO_AM_I Register
  error = MPU6050_read (MPU6050_WHO_AM_I, &c, 1);
  //F() macro stores on FLASH Memory rather than both SRAM and Flash Memory (why is that the default?)
  Serial.print(F("WHO_AM_I : "));
  //Serial.print(data,(display type)
  Serial.print(c,HEX);
  Serial.print(F(", error = "));
  Serial.println(error,DEC);

  //Check 'sleep' bit
  error = MPU6050_read (MPU6050_PWR_MGMT_1, &c, 1);
  Serial.print(F("PWR_MGMT_1 : "));
  Serial.print(c,HEX);
  Serial.print(F(", error = "));
  Serial.println(error,DEC);

  //Change Gyro config register for FS_SEL
  MPU6050_write_reg(MPU6050_GYRO_CONFIG,MPU6050_FS_SEL_2000);
  //Check Gyro Config register
  error = MPU6050_read (MPU6050_GYRO_CONFIG, &c, 1);
  Serial.print(F("FS_SLEL3: "));
  Serial.println(c,BIN);
  Serial.println(print_binary(c));

  // Clear the 'sleep' bit to start the sensor.
  MPU6050_write_reg (MPU6050_PWR_MGMT_1, 0);

  //---------------------- SD Card Setup ------------------------//

  Serial.print("Initializing SD card...");

  // see if the card is present and can be initialized:
  if (!SD.begin(sdChipSelectPin)) {
    Serial.println("Card failed, or not present");
    // don't do anything more:
    return;
  }
  Serial.println("card initialized.");

  File dataFile = SD.open("datalog.txt", FILE_WRITE);

  // if the file is available, write to it:
  if (dataFile) {
    dataFile.close();
    // print to the serial port too:
    Serial.println("START");
  }

  //------------------- Button / Toggle / Debug Setup ----------//

  pinMode(writeSwitchPin, INPUT);
  pinMode(bluetoothSwitchPin, INPUT);
  pinMode(deleteSwitchPin, INPUT);
  pinMode(buttonPin, INPUT);
  pinMode(ledPin, OUTPUT);

  //-------------------- FileManagement ------------------------//

  //setMeta(0);
  //Serial.println("doing meta testing");
  //setMeta(10);
  //int test = readMeta();
  Serial.println(F("Init checking Meta File"));
  fileNumber = readMeta();
  if(fileNumber == -1)
  {
    setMeta(10);
    fileNumber = 10;
  }
  String temp = intToTextFile(fileNumber);
  temp.toCharArray(currentFile, sizeof(currentFile));

}

double runningSum;
double runningSamples[10];
int runningSampleCounter = 0;

double sum = 0;
double spinThreshold = 0.75;
int changeThreshold = 5000;
long beginningOfTime;

double rollOver = 320000;

void loop()
{
  digitalWrite(ledPin, writeSwitchState);

  int currentButtonValue = digitalRead(buttonPin);

  if (currentButtonValue != lastButtonState)
  {
    lastDebounceTime = millis();
  }

  if ((millis() - lastDebounceTime) > debounceDelay)
  {
    if (currentButtonValue != buttonState)
    {
      Serial.println("Button State Changed");
      if( currentButtonValue == 1 && buttonState == 0)
       {
         writeSwitchState = !writeSwitchState;
       }

      buttonState = currentButtonValue;


      }
   }

  if(BLUETOOTHCONTROLLED)
  {
    if(bluetooth.available())
    {
      char gotten = bluetooth.read();
      Serial.println(String(gotten));
      switch(gotten)
      {
        //write to file
      case 'w':
	Serial.println(F("WWWWWWWWWWWWWWWWWWWWWWWWWWWWWWWWWWWWWWWWWWW"));
        writeSwitchState = 1;
        bluetoothSwitchState = 0;
        deleteSwitchState = 0;
        break;
        //send file over bluetooth
      case 'b':
	Serial.println(F("BBBBBBBBBBBBBBBBBBBBBBBBBBBBBBBBBBBBBBBBBBB"));
        writeSwitchState = 0;
        bluetoothSwitchState = 1;
        deleteSwitchState = 0;
        break;
        //delete file
      case 'd':
	Serial.println(F("DDDDDDDDDDDDDDDDDDDDDDDDDDDDDDDDDDDDDDDDDDDD"));
        writeSwitchState = 0;
        bluetoothSwitchState = 0;
        deleteSwitchState = 1;
        break;
        //do nothing
      case 'i':
	Serial.println(F("IIIIIIIIIIIIIIIIIIIIIIIIIIIIIIIIIIIIIIIIIII"));
        writeSwitchState = 0;
        bluetoothSwitchState = 0;
        deleteSwitchState = 0;
        break;

      default:
        Serial.println(F("THIS SHOULD NOT HAPPEN ~~~~~~~~~~~~~~~~~~"));
        break;
      }
    }
  }
  else
  {
    writeSwitchState = digitalRead(writeSwitchPin);
    bluetoothSwitchState = digitalRead(bluetoothSwitchPin);
    deleteSwitchState = digitalRead(deleteSwitchPin);

  }




  //Check if we should be logging to SD card from switch
  if(writeSwitchState)
  {
    if(!writeBreak)
    {
	Serial.println("Entering writeSwitchState");
        sum = 0;
        runningSampleCounter = 0;
        runningSum = 0;
        for(int i = 0; i < 10; i++)
        {
          runningSamples[i] = 0;
        }
        Serial.println(rollOver);
        beginningOfTime = millis();
        lastSpin = millis();
    }
    writeBreak = true;

    int error;
    double dT;
    accel_t_gyro_union accel_t_gyro;

    //Debug information
    //Serial.println(F(""));
    //Serial.println(F("MPU-6050"));

    // Read the raw values.
    // Read 14 bytes at once,
    // containing acceleration, temperature and gyro.
    // With the default settings of the MPU-6050,
    // there is no filter enabled, and the values
    // are not very stable.
    error = MPU6050_read (MPU6050_ACCEL_XOUT_H, (uint8_t *) &accel_t_gyro, sizeof(accel_t_gyro));
    //Serial.print(F("Read accel, temp and gyro, error = "));
    //Serial.println(error,DEC);


    // Swap all high and low bytes.
    // After this, the registers values are swapped,
    // so the structure name like x_accel_l does no
    // longer contain the lower byte.
    uint8_t swap;
    #define SWAP(x,y) swap = x; x = y; y = swap

    SWAP (accel_t_gyro.reg.x_accel_h, accel_t_gyro.reg.x_accel_l);
    SWAP (accel_t_gyro.reg.y_accel_h, accel_t_gyro.reg.y_accel_l);
    SWAP (accel_t_gyro.reg.z_accel_h, accel_t_gyro.reg.z_accel_l);
    SWAP (accel_t_gyro.reg.t_h, accel_t_gyro.reg.t_l);
    SWAP (accel_t_gyro.reg.x_gyro_h, accel_t_gyro.reg.x_gyro_l);
    SWAP (accel_t_gyro.reg.y_gyro_h, accel_t_gyro.reg.y_gyro_l);
    SWAP (accel_t_gyro.reg.z_gyro_h, accel_t_gyro.reg.z_gyro_l);


    // make a string for assembling the data to log:
    String dataString = String(accel_t_gyro.value.x_gyro) + ',' +
      String(accel_t_gyro.value.y_gyro) + ',' +
      String(accel_t_gyro.value.z_gyro);

    // open the file. note that only one file can be open at a time,
    // so you have to close this one before opening another.

      sum = sum + accel_t_gyro.value.y_gyro;
      if(sum >= rollOver || sum <= -rollOver)
      {
        File dataFile = SD.open(currentFile, FILE_WRITE);

        // if the file is available, write to it:
        if (dataFile)
        {
          long currentSpin = millis();
          dataFile.print(currentSpin - lastSpin);
          lastSpin = currentSpin;
          dataFile.print(" ");
          dataFile.close();
          // print to the serial port too:
          //Serial.println(dataString);
        }

        if(sum > 0)
        {
          sum = sum - rollOver;
        } else
        {
           sum = sum + rollOver;
        }


      }
      Serial.print("Sum: ");
      Serial.println(sum);
      Serial.println();
//
//
//    runningSum = runningSum + accel_t_gyro.value.y_gyro - runningSamples[runningSampleCounter];
//    runningSamples[runningSampleCounter] = accel_t_gyro.value.y_gyro;
//
//    runningSampleCounter++;
//    if(runningSampleCounter == 10)
//    {
//      runningSampleCounter = 0;
//    }
//    Serial.print("Sum: ");
//    Serial.println(sum);
//      Serial.println();
//    Serial.print("Running Sum:");
//    Serial.println(runningSum);
//    if((sum <= 0 && runningSum < 0) || (sum >= 0 && runningSum > 0))
//    {
//      sum = sum + accel_t_gyro.value.y_gyro;
//      if(abs(sum) >= 360*250)
//      {
//        File dataFile = SD.open(currentFile, FILE_WRITE);
//
//        // if the file is available, write to it:
//        if (dataFile)
//        {
//          dataFile.print(millis() - beginningOfTime);
//          dataFile.print(" ");
//          dataFile.close();
//          // print to the serial port too:
//          //Serial.println(dataString);
//        }
//        sum = sum - 360*250;
//      }
//      else if(abs(runningSum) > changeThreshold*250)
//      {
//        sum = runningSum;
//        for(int i = 0; i < 10; i++)
//        {
//          runningSamples[i] = 0;
//        }
//        runningSum = 0;
//        if(abs(sum) >= 360*spinThreshold*250)
//        {
//          File dataFile = SD.open(currentFile, FILE_WRITE);
//
//          // if the file is available, write to it:
//          if (dataFile)
//          {
//            dataFile.print(millis() - beginningOfTime);
//            dataFile.print(" ");
//            dataFile.close();
//            // print to the serial port too:
//            //Serial.println(dataString);
//          }
//        }
//      }
//    }
  }
  else
  {
    if(writeBreak)
    {
//      if(abs(sum) >= 360*250)
//      {
//        File dataFile = SD.open(currentFile, FILE_WRITE);
//
//        // if the file is available, write to it:
//        if (dataFile)
//        {
//          dataFile.print(millis() - beginningOfTime);
//          dataFile.print(" ");
//          dataFile.close();
//          // print to the serial port too:
//          //Serial.println(dataString);
//        }
//      }

      File dataFile = SD.open(currentFile, FILE_WRITE);

      // if the file is available, write to it:
      if (dataFile)
      {
        dataFile.println("");
        dataFile.close();
        // print to the serial port too:
        //Serial.println("STOPCOLLECTING");
      }

      //Get old meta value and increase it by 1 then set Meta to be that value
      fileNumber = readMeta();
      fileNumber++;
      setMeta(fileNumber);
      Serial.print("Does meta exist?:");
      Serial.println(SD.exists("meta.txt"));

      //Set currentFile to be "fileNumber".txt
      String temp = intToTextFile(fileNumber);
      temp.toCharArray(currentFile, sizeof(currentFile));

      writeBreak = false;
    }

    delay(100);

    if(bluetoothSwitchState)
    {
      Serial.println(F("Attempting to open file to send over bluetooth"));

      int i = 10;
      fileNumber = readMeta();
      char fileToSend[14];
      Serial.println(F("File loop _______________"));
      //Loop from file 0.txt to "meta.value".txt till you find a file that exists
      while(i < fileNumber && !SD.exists(fileToSend))
      {
	String temp = intToTextFile(i);
	temp.toCharArray(fileToSend, sizeof(fileToSend));
	i++;
      }
      //Send the file that you found
      File dataFile = SD.open(fileToSend);

      if(dataFile)
      {
        Serial.println(F("File available, sending"));
        while(dataFile.available())
        {
          byte data = dataFile.read();
          bluetooth.write(data);
        }

        dataFile.close();
      }
      else
      {
        Serial.println(F("No file available"));
      }
      bluetoothSwitchState = 0;
    }
    if(deleteSwitchState)
    {
      Serial.println(F("Trying to delete file"));
      int i = 10;
      fileNumber = readMeta();
      char fileToDelete[14];

      //Loop from file 0.txt to "meta.value".txt till you find a file that exists
      while(i < fileNumber && !SD.exists(fileToDelete))
      {
	String temp = intToTextFile(i);
	temp.toCharArray(fileToDelete, sizeof(fileToDelete));
	i++;
      }

      if(SD.remove(fileToDelete))
      {
	Serial.println(F("File got deleted"));
      }
      else
      {
	Serial.println(F("PROBLEM OH NO, File did not get deleted"));
      }
      deleteSwitchState = 0;
    }
  }
  lastButtonState = currentButtonValue;
}


//MPU6050 READ/WRITE

// --------------------------------------------------------
// MPU6050_read
//
// This is a common function to read multiple bytes
// from an I2C device.
//
// It uses the boolean parameter for Wire.endTransMission()
// to be able to hold or release the I2C-bus.
// This is implemented in Arduino 1.0.1.
//
// Only this function is used to read.
// There is no function for a single byte.
//

int MPU6050_read(int start, uint8_t *buffer, int size)
{
  int i, n, error;

  Wire.beginTransmission(MPU6050_I2C_ADDRESS);
  n = Wire.write(start);
  if (n != 1)
    return (-10);

  n = Wire.endTransmission(false);    // hold the I2C-bus
  if (n != 0)
    return (n);

  // Third parameter is true: relase I2C-bus after data is read.
  Wire.requestFrom(MPU6050_I2C_ADDRESS, size, true);
  i = 0;
  while(Wire.available() && i<size)
  {
    buffer[i++]=Wire.read();
  }
  if ( i != size)
    return (-11);

  return (0);  // return : no error
}

// --------------------------------------------------------
// MPU6050_write
//
// This is a common function to write multiple bytes to an I2C device.
//
// If only a single register is written,
// use the function MPU_6050_write_reg().
//
// Parameters:
//   start : Start address, use a define for the register
//   pData : A pointer to the data to write.
//   size  : The number of bytes to write.
//
// If only a single register is written, a pointer
// to the data has to be used, and the size is
// a single byte:
//   int data = 0;        // the data to write
//   MPU6050_write (MPU6050_PWR_MGMT_1, &c, 1);
//
int MPU6050_write(int start, const uint8_t *pData, int size)
{
  int n, error;

  Wire.beginTransmission(MPU6050_I2C_ADDRESS);
  n = Wire.write(start);        // write the start address
  if (n != 1)
    return (-20);

  n = Wire.write(pData, size);  // write data bytes
  if (n != size)
    return (-21);

  error = Wire.endTransmission(true); // release the I2C-bus
  if (error != 0)
    return (error);

  return (0);         // return : no error
}

// --------------------------------------------------------
// MPU6050_write_reg
//
// An extra function to write a single register.
// It is just a wrapper around the MPU_6050_write()
// function, and it is only a convenient function
// to make it easier to write a single register.
//
int MPU6050_write_reg(int reg, uint8_t data)
{
  int error;

  error = MPU6050_write(reg, &data, 1);

  return (error);
}

//Prints a uint8_t as binary rather with leading zeros
char* print_binary(uint8_t data)
{
  uint8_t mask = 128;
  char finalString[9];

  uint8_t i;

  for(i = 0; i < 8; i++){
    if(data & mask){
      finalString[i] = '1';
    }
    else {
      finalString[i] = '0';
    }

    mask = mask >> 1;
  }

  finalString[8] = '\0';

  return finalString;

}

int readMeta() {
  Serial.println(F("Checking meta file"));
  File meta = SD.open("meta.txt");
  int metaInt = -1;
  if (meta)
  {
    Serial.println(F("Creating int from meta file"));
    char metaChars[10];
    int i = 0;
    while(meta.available())
    {
      metaChars[i] = meta.read();
      i++;
    }
    metaChars[i] = '\0';
    metaInt = atoi(metaChars);
    Serial.println(String(metaInt));
  }
  meta.close();
  return metaInt;

}

void setMeta(int value)
{
  SD.remove("meta.txt");
  File meta = SD.open("meta.txt", FILE_WRITE);

  if(meta)
  {
    Serial.print(F("Setting Meta to:"));
    Serial.println(String(value));
    meta.print(String(value));
    meta.close();
  }

}

String intToTextFile(int value)
{
  String textFile;
  textFile = String(value);
  textFile.concat(".txt");

  return textFile;
}

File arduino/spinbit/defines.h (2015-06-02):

// The name of the sensor is "MPU-6050".
// For program code, I omit the '-',
// therefor I use the name "MPU6050....".

// Register names according to the datasheet.
// According to the InvenSense document
// "MPU-6000 and MPU-6050 Register Map
// and Descriptions Revision 3.2", there are no registers
// at 0x02 ... 0x18, but according other information
// the registers in that unknown area are for gain
// and offsets.
//
#define MPU6050_AUX_VDDIO          0x01   // R/W
#define MPU6050_SMPLRT_DIV         0x19   // R/W
#define MPU6050_CONFIG             0x1A   // R/W
#define MPU6050_GYRO_CONFIG        0x1B   // R/W
#define MPU6050_ACCEL_CONFIG       0x1C   // R/W
#define MPU6050_FF_THR             0x1D   // R/W
#define MPU6050_FF_DUR             0x1E   // R/W
#define MPU6050_MOT_THR            0x1F   // R/W
#define MPU6050_MOT_DUR            0x20   // R/W
#define MPU6050_ZRMOT_THR          0x21   // R/W
#define MPU6050_ZRMOT_DUR          0x22   // R/W
#define MPU6050_FIFO_EN            0x23   // R/W
#define MPU6050_I2C_MST_CTRL       0x24   // R/W
#define MPU6050_I2C_SLV0_ADDR      0x25   // R/W
#define MPU6050_I2C_SLV0_REG       0x26   // R/W
#define MPU6050_I2C_SLV0_CTRL      0x27   // R/W
#define MPU6050_I2C_SLV1_ADDR      0x28   // R/W
#define MPU6050_I2C_SLV1_REG       0x29   // R/W
#define MPU6050_I2C_SLV1_CTRL      0x2A   // R/W
#define MPU6050_I2C_SLV2_ADDR      0x2B   // R/W
#define MPU6050_I2C_SLV2_REG       0x2C   // R/W
#define MPU6050_I2C_SLV2_CTRL      0x2D   // R/W
#define MPU6050_I2C_SLV3_ADDR      0x2E   // R/W
#define MPU6050_I2C_SLV3_REG       0x2F   // R/W
#define MPU6050_I2C_SLV3_CTRL      0x30   // R/W
#define MPU6050_I2C_SLV4_ADDR      0x31   // R/W
#define MPU6050_I2C_SLV4_REG       0x32   // R/W
#define MPU6050_I2C_SLV4_DO        0x33   // R/W
#define MPU6050_I2C_SLV4_CTRL      0x34   // R/W
#define MPU6050_I2C_SLV4_DI        0x35   // R  
#define MPU6050_I2C_MST_STATUS     0x36   // R
#define MPU6050_INT_PIN_CFG        0x37   // R/W
#define MPU6050_INT_ENABLE         0x38   // R/W
#define MPU6050_INT_STATUS         0x3A   // R  
#define MPU6050_ACCEL_XOUT_H       0x3B   // R  
#define MPU6050_ACCEL_XOUT_L       0x3C   // R  
#define MPU6050_ACCEL_YOUT_H       0x3D   // R  
#define MPU6050_ACCEL_YOUT_L       0x3E   // R  
#define MPU6050_ACCEL_ZOUT_H       0x3F   // R  
#define MPU6050_ACCEL_ZOUT_L       0x40   // R  
#define MPU6050_TEMP_OUT_H         0x41   // R  
#define MPU6050_TEMP_OUT_L         0x42   // R  
#define MPU6050_GYRO_XOUT_H        0x43   // R  
#define MPU6050_GYRO_XOUT_L        0x44   // R  
#define MPU6050_GYRO_YOUT_H        0x45   // R  
#define MPU6050_GYRO_YOUT_L        0x46   // R  
#define MPU6050_GYRO_ZOUT_H        0x47   // R  
#define MPU6050_GYRO_ZOUT_L        0x48   // R  
#define MPU6050_EXT_SENS_DATA_00   0x49   // R  
#define MPU6050_EXT_SENS_DATA_01   0x4A   // R  
#define MPU6050_EXT_SENS_DATA_02   0x4B   // R  
#define MPU6050_EXT_SENS_DATA_03   0x4C   // R  
#define MPU6050_EXT_SENS_DATA_04   0x4D   // R  
#define MPU6050_EXT_SENS_DATA_05   0x4E   // R  
#define MPU6050_EXT_SENS_DATA_06   0x4F   // R  
#define MPU6050_EXT_SENS_DATA_07   0x50   // R  
#define MPU6050_EXT_SENS_DATA_08   0x51   // R  
#define MPU6050_EXT_SENS_DATA_09   0x52   // R  
#define MPU6050_EXT_SENS_DATA_10   0x53   // R  
#define MPU6050_EXT_SENS_DATA_11   0x54   // R  
#define MPU6050_EXT_SENS_DATA_12   0x55   // R  
#define MPU6050_EXT_SENS_DATA_13   0x56   // R  
#define MPU6050_EXT_SENS_DATA_14   0x57   // R  
#define MPU6050_EXT_SENS_DATA_15   0x58   // R  
#define MPU6050_EXT_SENS_DATA_16   0x59   // R  
#define MPU6050_EXT_SENS_DATA_17   0x5A   // R  
#define MPU6050_EXT_SENS_DATA_18   0x5B   // R  
#define MPU6050_EXT_SENS_DATA_19   0x5C   // R  
#define MPU6050_EXT_SENS_DATA_20   0x5D   // R  
#define MPU6050_EXT_SENS_DATA_21   0x5E   // R  
#define MPU6050_EXT_SENS_DATA_22   0x5F   // R  
#define MPU6050_EXT_SENS_DATA_23   0x60   // R  
#define MPU6050_MOT_DETECT_STATUS  0x61   // R  
#define MPU6050_I2C_SLV0_DO        0x63   // R/W
#define MPU6050_I2C_SLV1_DO        0x64   // R/W
#define MPU6050_I2C_SLV2_DO        0x65   // R/W
#define MPU6050_I2C_SLV3_DO        0x66   // R/W
#define MPU6050_I2C_MST_DELAY_CTRL 0x67   // R/W
#define MPU6050_SIGNAL_PATH_RESET  0x68   // R/W
#define MPU6050_MOT_DETECT_CTRL    0x69   // R/W
#define MPU6050_USER_CTRL          0x6A   // R/W
#define MPU6050_PWR_MGMT_1         0x6B   // R/W
#define MPU6050_PWR_MGMT_2         0x6C   // R/W
#define MPU6050_FIFO_COUNTH        0x72   // R/W
#define MPU6050_FIFO_COUNTL        0x73   // R/W
#define MPU6050_FIFO_R_W           0x74   // R/W
#define MPU6050_WHO_AM_I           0x75   // R
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

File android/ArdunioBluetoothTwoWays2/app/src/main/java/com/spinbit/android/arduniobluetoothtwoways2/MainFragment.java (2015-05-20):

package com.spinbit.android.arduniobluetoothtwoways2;

import android.app.Fragment;
import android.bluetooth.BluetoothAdapter;
import android.bluetooth.BluetoothDevice;
import android.bluetooth.BluetoothSocket;
import android.content.Intent;
import android.os.Build;
import android.os.Bundle;
import android.os.Handler;
import android.os.Message;
import android.util.Log;
import android.view.LayoutInflater;
import android.view.View;
import android.view.ViewGroup;
import android.widget.Button;
import android.widget.TextView;
import android.widget.Toast;

import java.io.IOException;
import java.io.InputStream;
import java.io.OutputStream;
import java.lang.reflect.Method;
import java.util.Set;
import java.util.UUID;

/*
 * Created by isaacperry on 5/10/15.
 */
public class MainFragment extends Fragment {

    //************************************876   uAS*****************************************
    // Views
    //*****************************************************************************
    private Button mViewHistoryButton;
    private Button mLogButton;
    private TextView mResponseTextView;

    //*****************************************************************************
    //*****************************************************************************

    //*****************************************************************************
    // Bluetooth Entities
    //*****************************************************************************
    private Handler bluetoothHandler;
    private static final String TAG = "bluetooth2";
    final int RECIEVE_MESSAGE = 1;        // Status  for Handler
    private BluetoothAdapter btAdapter = null;
    private BluetoothSocket btSocket = null;
    private StringBuilder sb = new StringBuilder();

    private ConnectedThread mConnectedThread;

    // SPP UUID service
    private static final UUID MY_UUID = UUID.fromString("00001101-0000-1000-8000-00805F9B34FB");

    // MAC-address of Bluetooth module (you must edit this line)
    // private static String address = "00:06:66:74:80:AE";
    //*****************************************************************************
    //*****************************************************************************

    @Override
    public void onCreate(Bundle savedInstanceState) {
        super.onCreate(savedInstanceState);
        // save this instance when it would otherwise be destroyed: preserve bluetooth status
        setRetainInstance(true);
        //*****************************************************************************
        // Initialize Bluetooth
        //*****************************************************************************
        bluetoothHandler = new BluetoothHandler();

        btAdapter = BluetoothAdapter.getDefaultAdapter();       // get Bluetooth adapter
        checkBTState();
        initiateConnection();
        //*****************************************************************************
        //*****************************************************************************
    }


    @Override
    public View onCreateView(LayoutInflater inflater, ViewGroup parent, Bundle savedInstanceState) {
        // inflate the view
        View v = inflater.inflate(R.layout.fragment_main, parent, false);

        //*****************************************************************************
        // Wiring up the view objects
        //*****************************************************************************
        mViewHistoryButton = (Button) v.findViewById(R.id.viewHistory);
        mViewHistoryButton.setOnClickListener(new View.OnClickListener() {
            @Override
            public void onClick(View view) {
                Intent i = new Intent(getActivity(), SpinListActivity.class);
                startActivity(i);
            }
        });

        mLogButton = (Button) v.findViewById(R.id.logButton);
        mLogButton.setOnClickListener(new View.OnClickListener() {
            @Override
            public void onClick(View view) {
                mConnectedThread.write("R");
            }
        });

        mResponseTextView = (TextView) v.findViewById(R.id.responseTextView);

        //*****************************************************************************
        //*****************************************************************************

        return v;
    }

    //*****************************************************************************
    // Other Fragment Lifecycle Methods
    //*****************************************************************************
    @Override
    public void onPause() {
        super.onPause();
        DanceHistory.get(getActivity()).saveHistory();
    }
    //*****************************************************************************
    //*****************************************************************************

    //*****************************************************************************
    // Bluetooth Helper Methods and Classes
    //*****************************************************************************
    private void initiateConnection() {
        Log.d(TAG, "...initiateConnection() - try connect...");

        // Set up a pointer to the remote node using it's address.
        BluetoothDevice device = null;
        // = btAdapter.getRemoteDevice(address);

        Set<BluetoothDevice> devices = btAdapter.getBondedDevices();


        for (BluetoothDevice b : devices) {
            if(b.getName().equals("E2H")) {
                device = b;
            }

        }


        // Two things are needed to make a connection:
        //   A MAC address, which we got above.
        //   A Service ID or UUID.  In this case we are using the
        //     UUID for SPP.

        Log.d(TAG, "creating a new socket");
        try {
            btSocket = createBluetoothSocket(device);
        } catch (IOException e) {
            errorExit("Fatal Error", "In onResume() and socket create failed: " + e.getMessage() + ".");
        }


        // Discovery is resource intensive.  Make sure it isn't going on
        // when you attempt to connect and pass your message.
        btAdapter.cancelDiscovery();

        // Establish the connection.  This will block until it connects.
        Log.d(TAG, "...Connecting...");

        try {
            btSocket.connect();
            Log.d(TAG, "....Connection ok...");
        } catch (IOException e) {
            try {
                btSocket.close();
            } catch (IOException e2) {
                errorExit("Fatal Error", "In onResume() and unable to close socket during connection failure" + e2.getMessage() + ".");
            }
        }

        // Create a data stream so we can talk to server.
        Log.d(TAG, "...Create Socket...");

        mConnectedThread = new ConnectedThread(btSocket);
        mConnectedThread.start();
    }
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

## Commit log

2015-04-28 Adding open source bluetooth and gyro design files
    [BOM nRF8001-Reference Layout_DCDC_rev1_0.xls, BOM nRF8001-Reference Layout_rev1_0.xls, Triple_Axis_Accelerometer_-_Gyro_Breakout_-_MPU-6050-GiantPanel-v12.brd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]
2015-04-28 Adding Gyro logging to serial
2015-05-05 Gyro Data writing to SD Card
2015-05-06 Now using better code to configure Gyro also has button on pin 7 to stop writing to sd
2015-05-09 Not currently working
2015-05-27 Board Files
    [spinbitboard.brd, spinbitboard.sch]
2015-05-28 Starting an overhall, branching to avoid bad commits
    [GyroToSd.ino]

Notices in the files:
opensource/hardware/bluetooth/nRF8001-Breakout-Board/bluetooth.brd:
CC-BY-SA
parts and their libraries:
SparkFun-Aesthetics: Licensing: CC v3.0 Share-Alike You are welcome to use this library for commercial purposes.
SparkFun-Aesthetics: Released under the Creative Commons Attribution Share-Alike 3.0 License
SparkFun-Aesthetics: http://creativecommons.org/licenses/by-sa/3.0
